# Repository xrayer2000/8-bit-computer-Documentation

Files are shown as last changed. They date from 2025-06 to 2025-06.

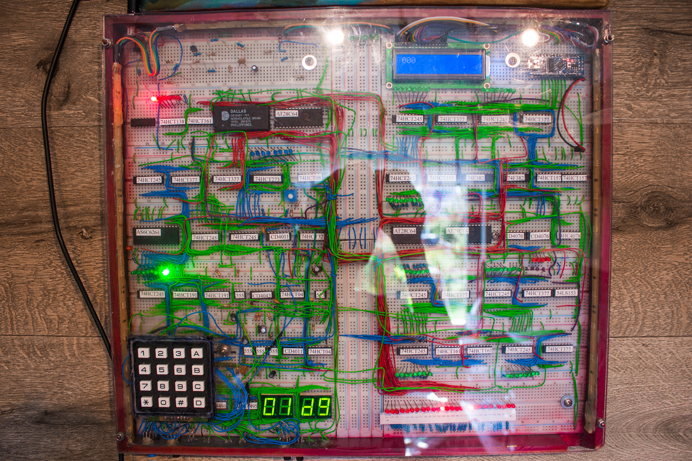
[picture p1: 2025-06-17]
Pictures/8-bit computer.jpg

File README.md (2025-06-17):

# LICENSE

## README

This project is licensed under the Creative Commons Attribution-NonCommercial 4.0 International License (CC BY-NC 4.0).

You are free to:
- Share (copy and redistribute the material in any medium or format)
- Adapt (remix, transform, and build upon the material)

Under the conditions that:
- You must give appropriate credit.
- You may not use the material for commercial purposes.

For full license details, see:  
[https://creativecommons.org/licenses/by-nc/4.0/](https://creativecommons.org/licenses/by-nc/4.0/)

---

## Creative Commons Attribution-NonCommercial 4.0 International (CC BY-NC 4.0)

Copyright (c) 2025 Emil

You are free to:
- Share — copy and redistribute the material in any medium or format
- Adapt — remix, transform, and build upon the material

Under the following terms:
- **Attribution** — You must give appropriate credit, provide a link to the license, and indicate if changes were made.
- **NonCommercial** — You may not use the material for commercial purposes.

No additional restrictions — You may not apply legal terms or technological measures that restrict others from doing anything the license permits.

Full license text:  
[https://creativecommons.org/licenses/by-nc/4.0/legalcode](https://creativecommons.org/licenses/by-nc/4.0/legalcode)

---

## How to attribute

If you use or adapt this project, please include the following attribution:

> “Project name” by Emil is licensed under CC BY-NC 4.0.  
> [https://creativecommons.org/licenses/by-nc/4.0/](https://creativecommons.org/licenses/by-nc/4.0/)

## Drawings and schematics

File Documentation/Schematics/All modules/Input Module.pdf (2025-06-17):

## I/O Pins

## Debouncer to 191

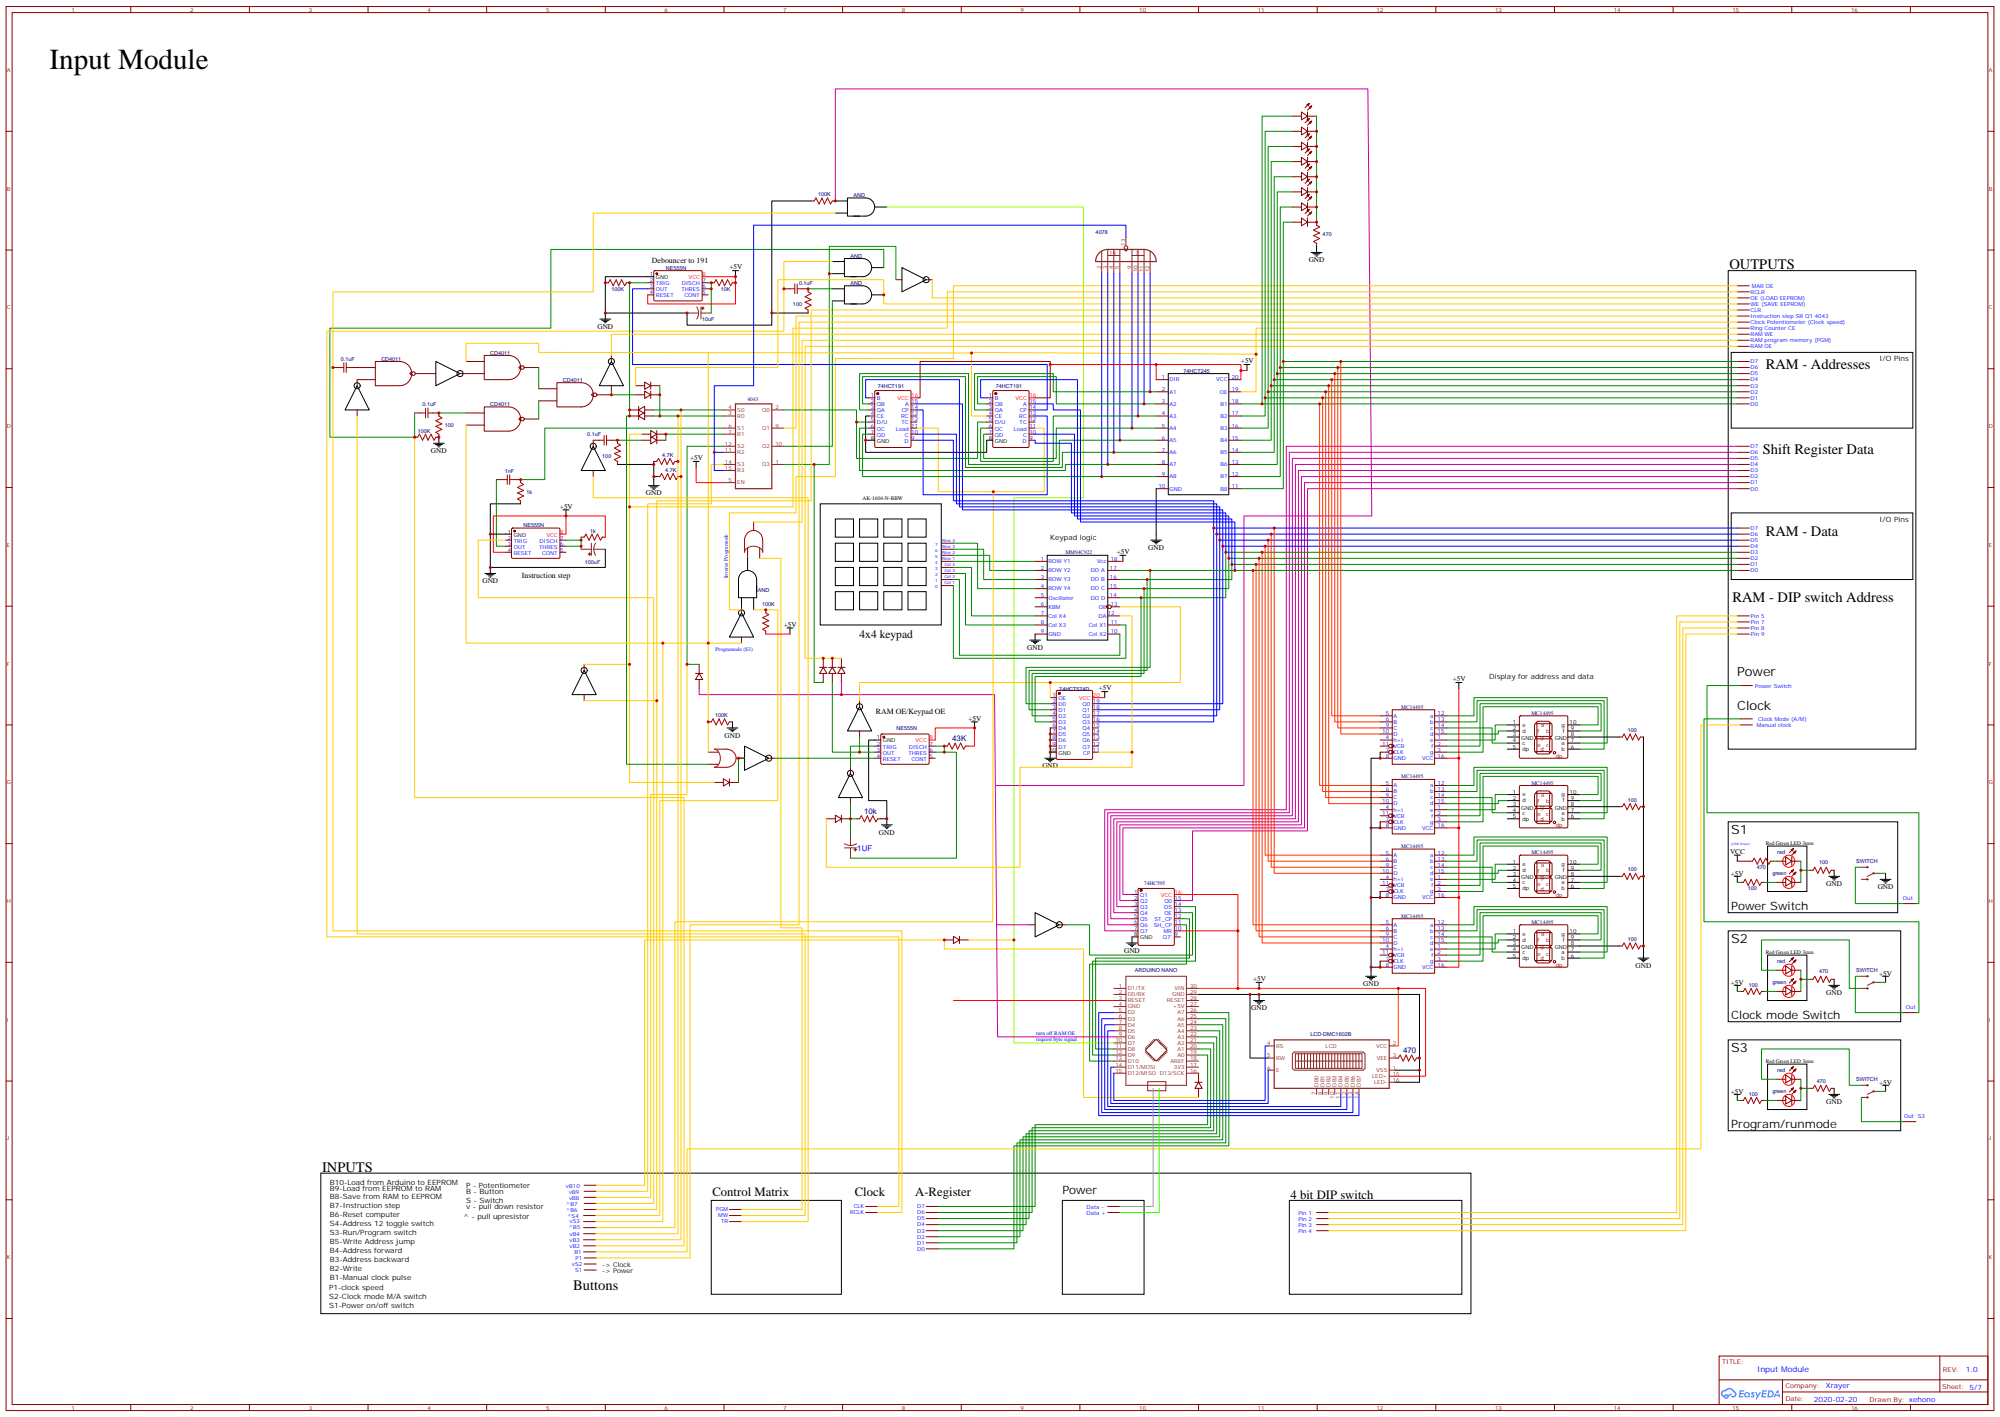
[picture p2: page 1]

Display for address and data

RAM OE/Keypad OE

turn off RAM OE
request byte signal

B10-Load from Arduino to EEPROM
B9-Load from EEPROM to RAM
B8-Save from RAM to EEPROM
B7-Instruction step
B6-Reset computer
S4-Address 12 toggle switch
S3-Run/Program switch
B5-Write Address jump
B4-Address forward
B3-Address backward
B2-Write
B1-Manual clock pulse
P1-clock speed
S2-Clock mode M/A switch
S1-Power on/off switch

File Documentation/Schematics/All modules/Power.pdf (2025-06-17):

# Power

# OUTPUTS

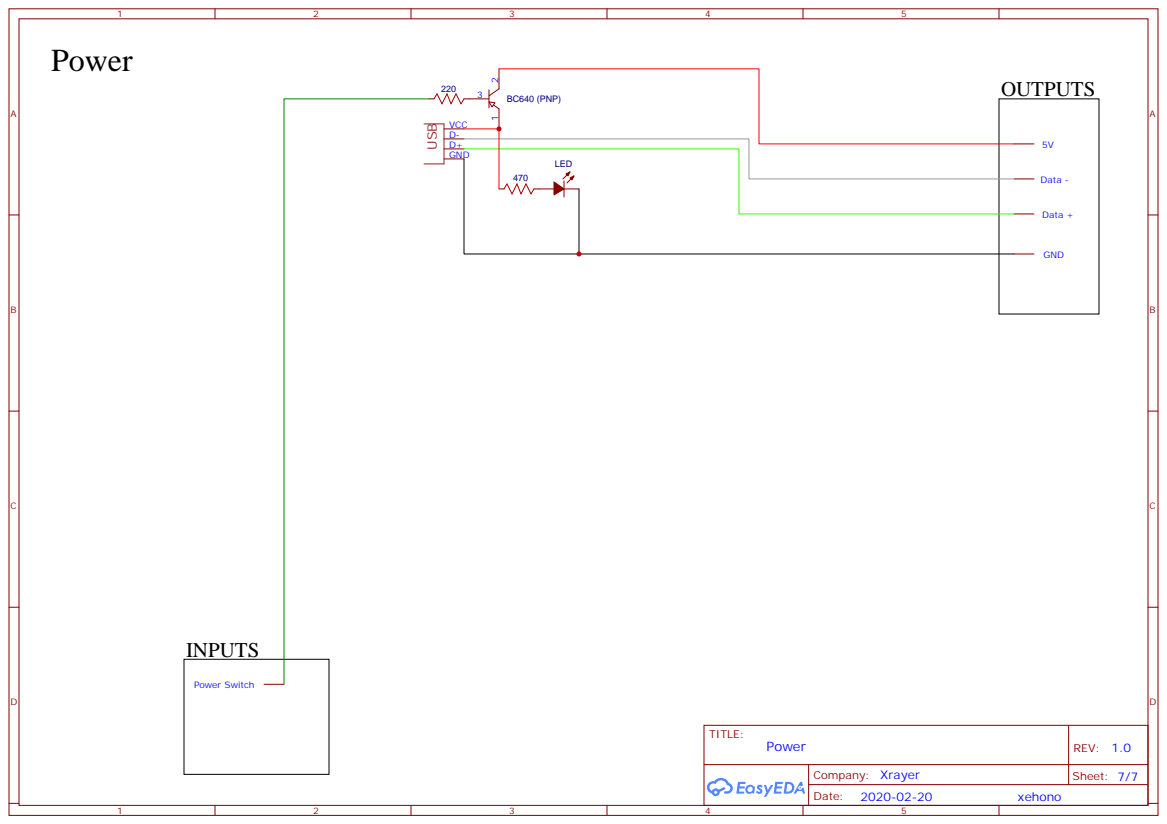
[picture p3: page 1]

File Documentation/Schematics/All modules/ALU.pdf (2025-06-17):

# ALU

# INPUTS

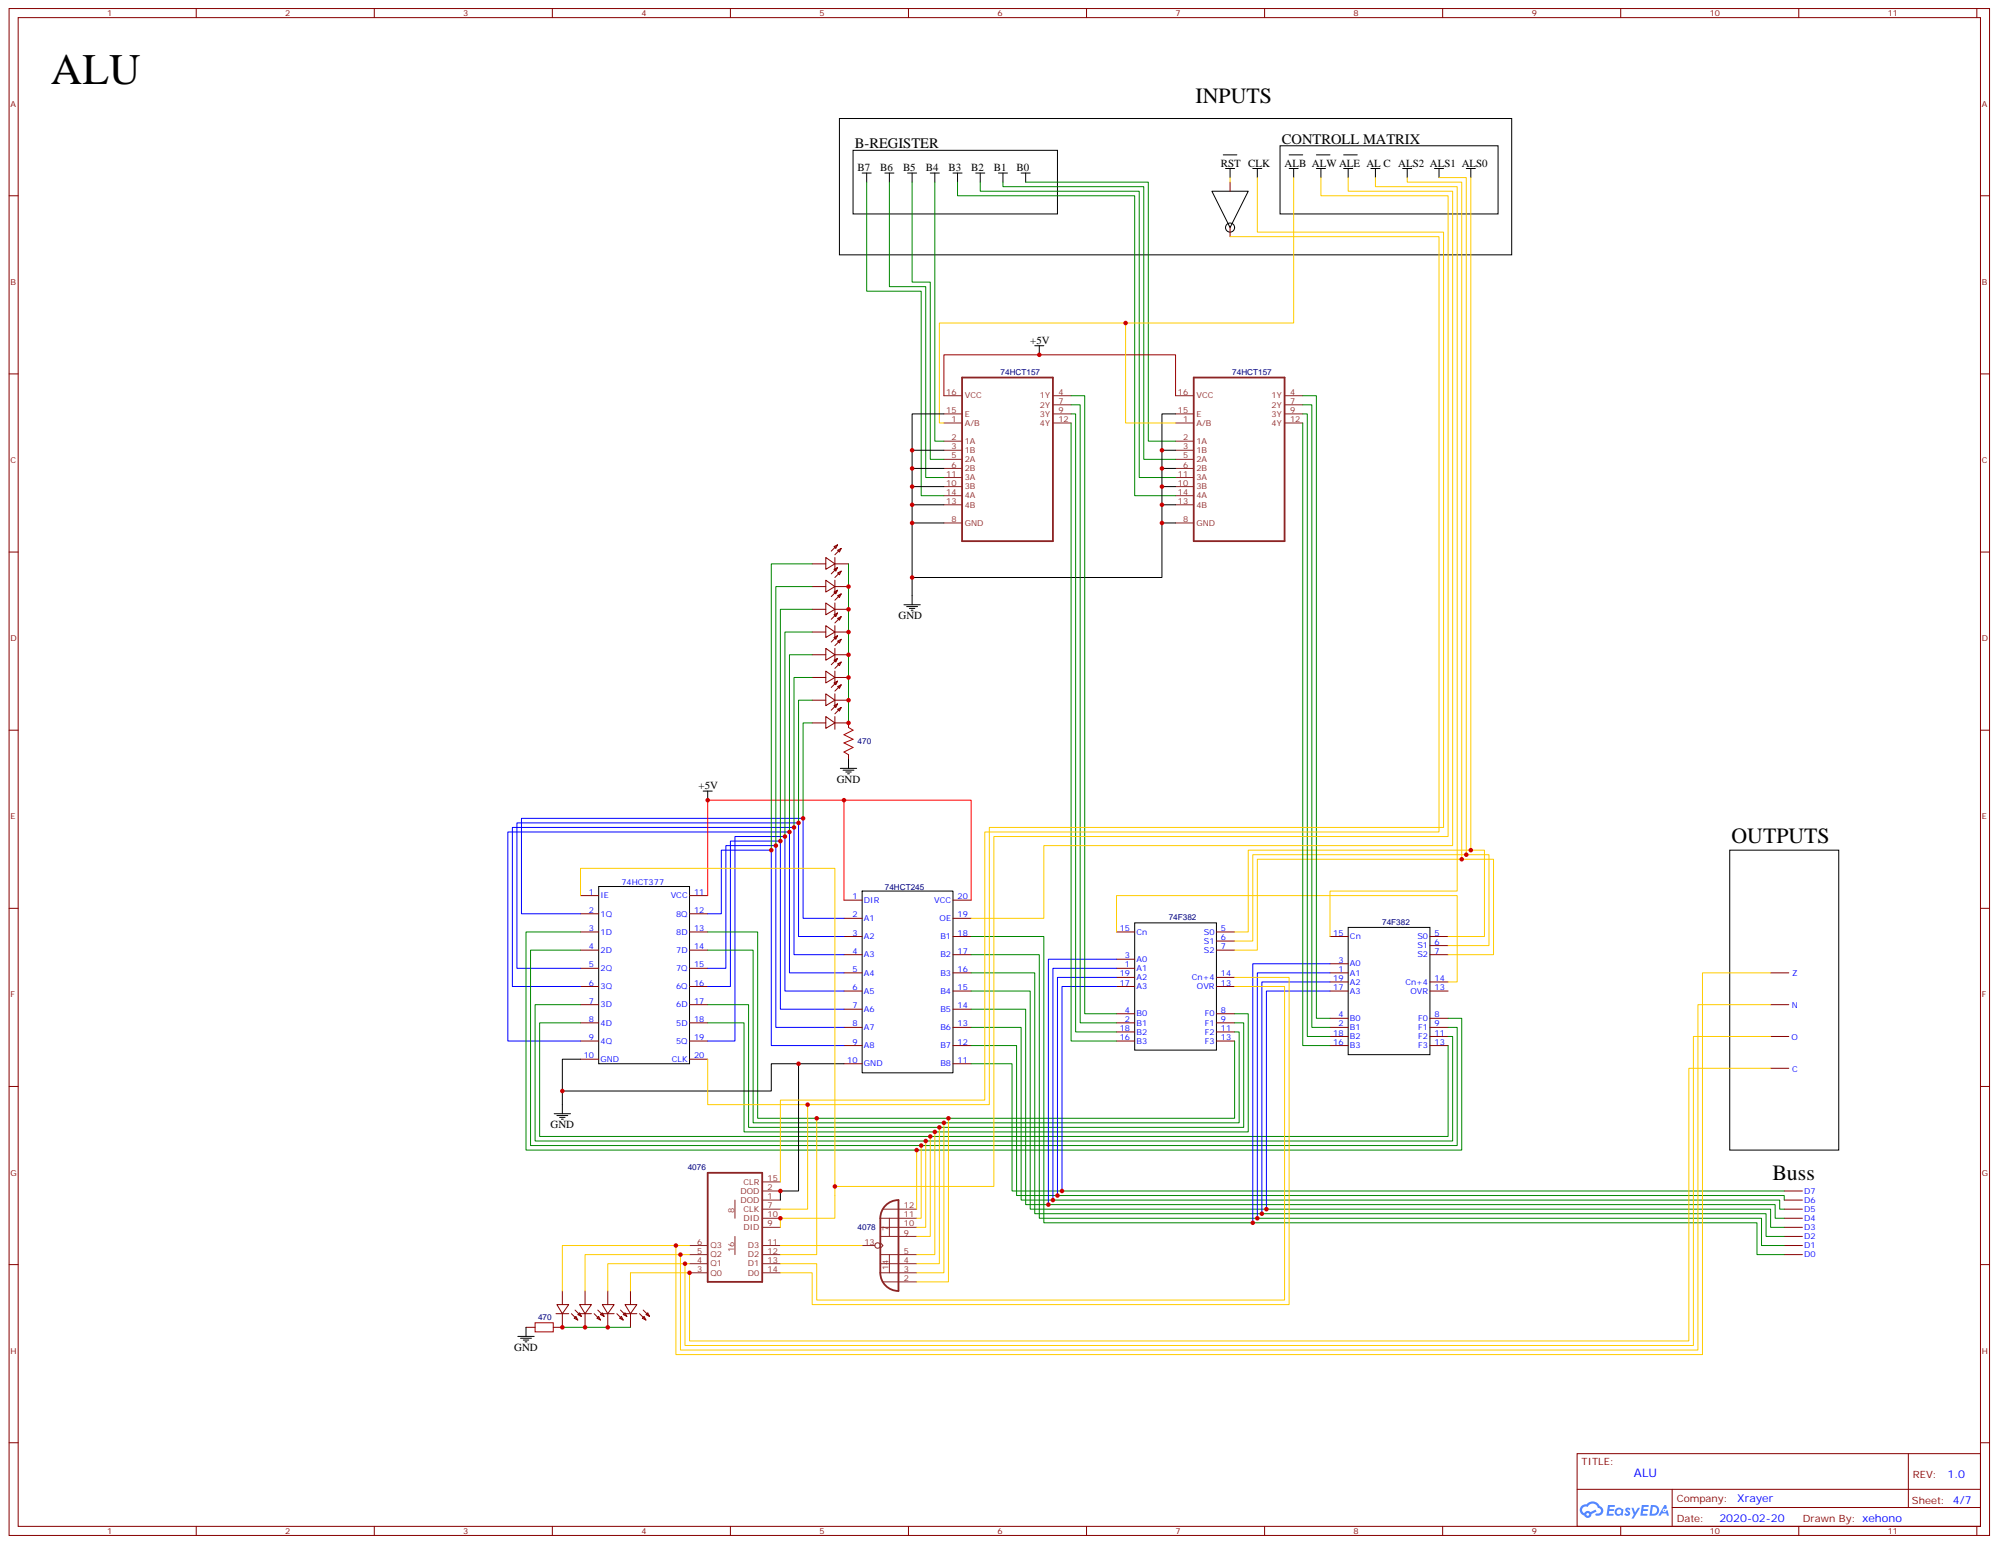
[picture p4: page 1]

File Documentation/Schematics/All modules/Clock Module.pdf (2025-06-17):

# OUTPUTS

# Clock Module

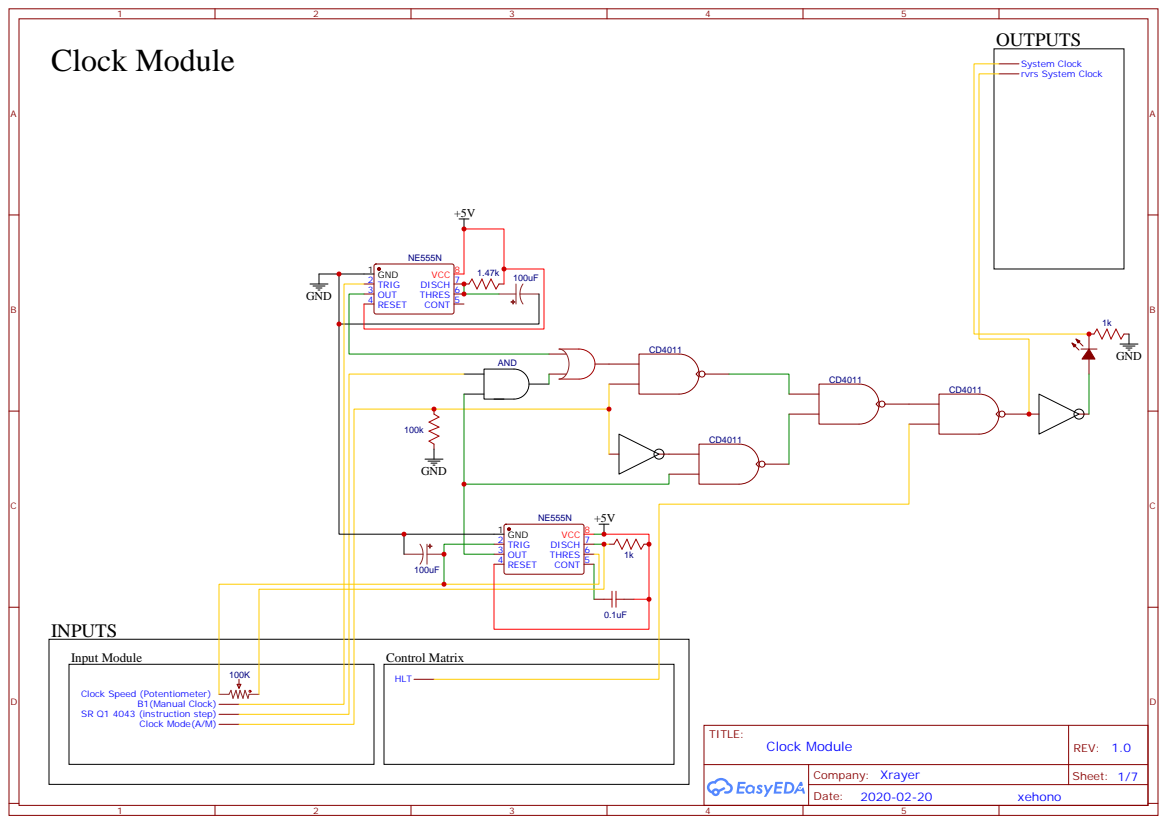
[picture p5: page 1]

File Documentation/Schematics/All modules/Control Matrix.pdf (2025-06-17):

## Control word

# Control Matrix

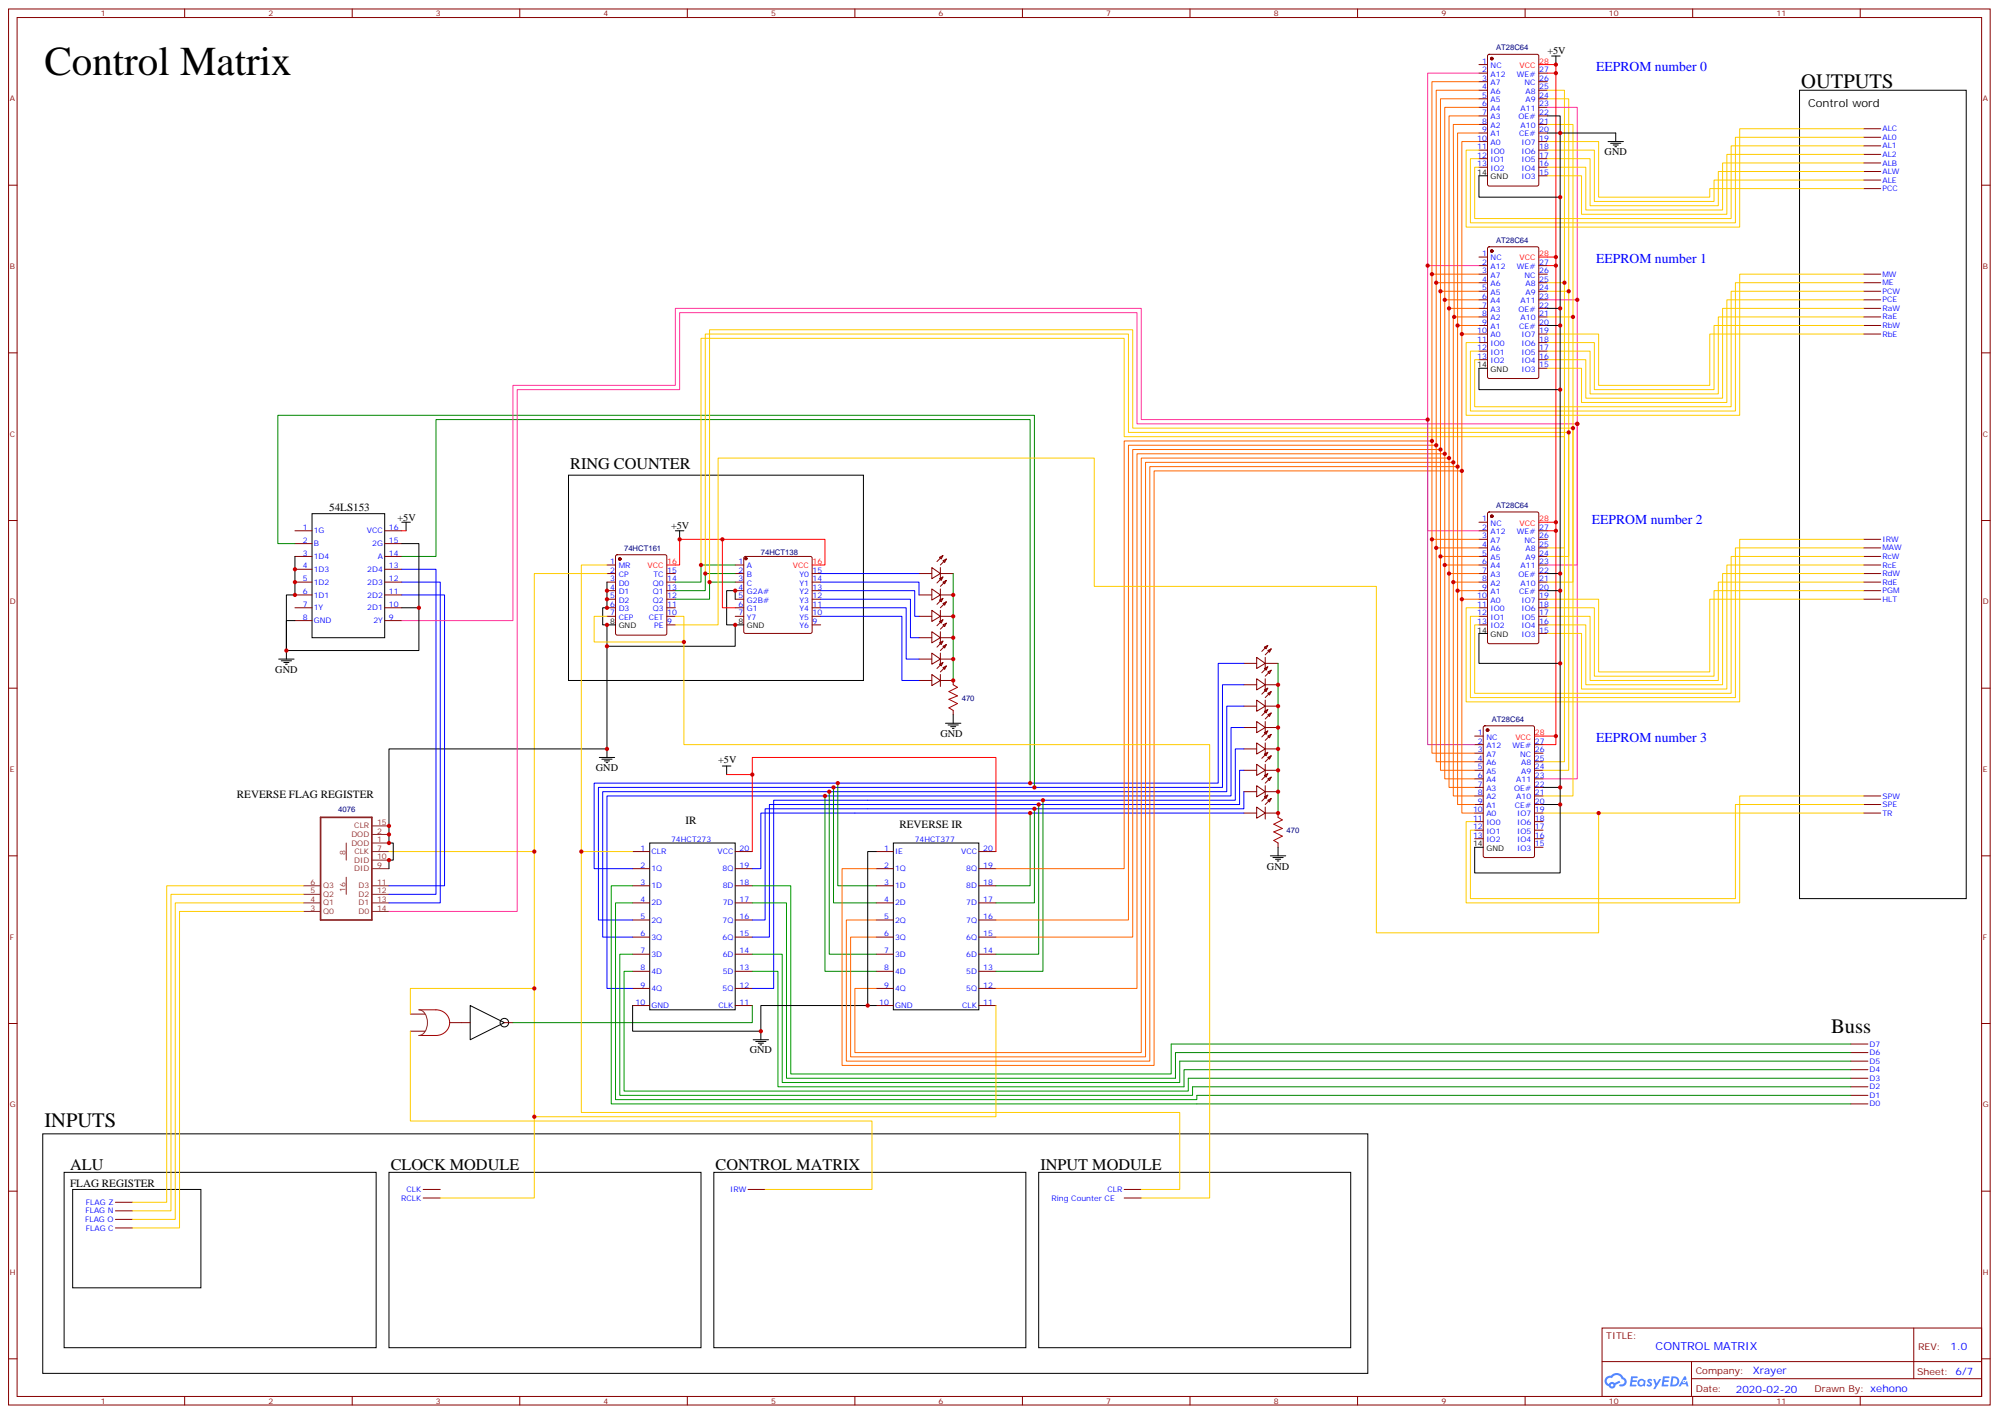
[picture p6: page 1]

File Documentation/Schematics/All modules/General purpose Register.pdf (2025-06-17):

# General purpose Register

# INPUTS

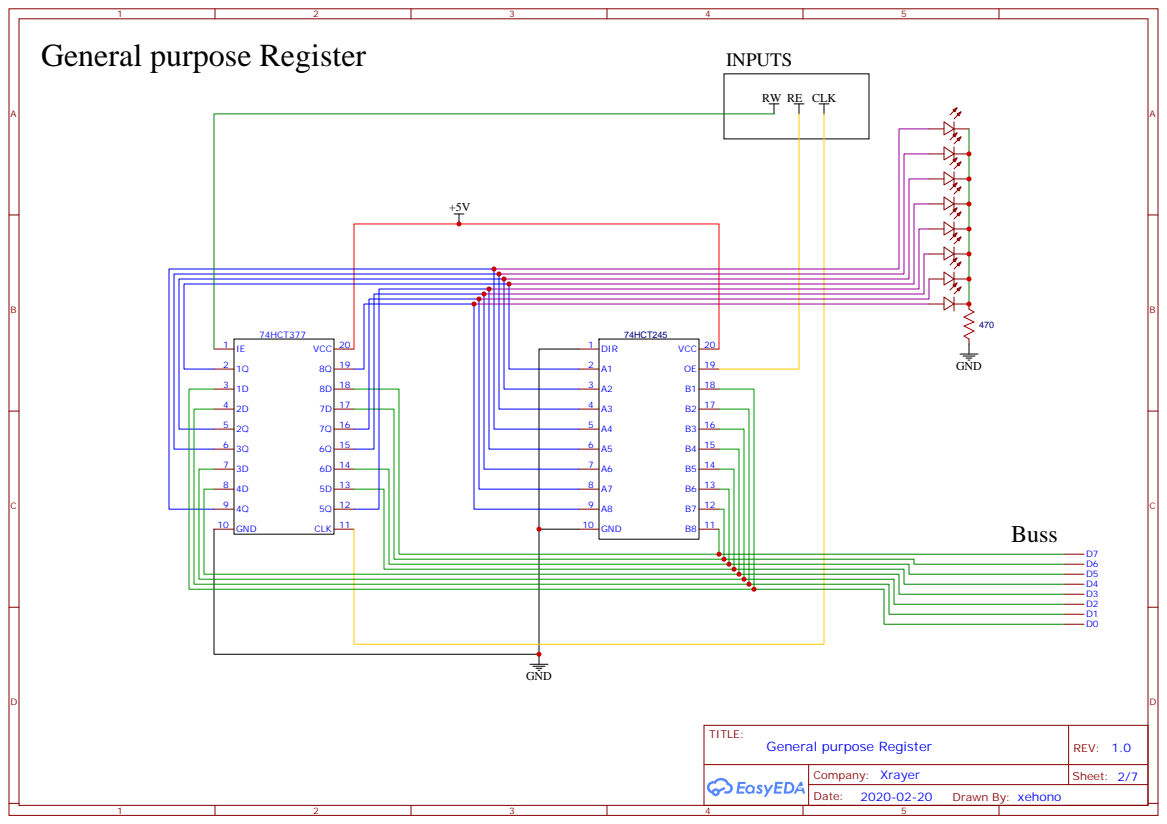
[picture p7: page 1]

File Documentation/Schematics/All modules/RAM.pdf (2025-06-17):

# MAR

# RAM

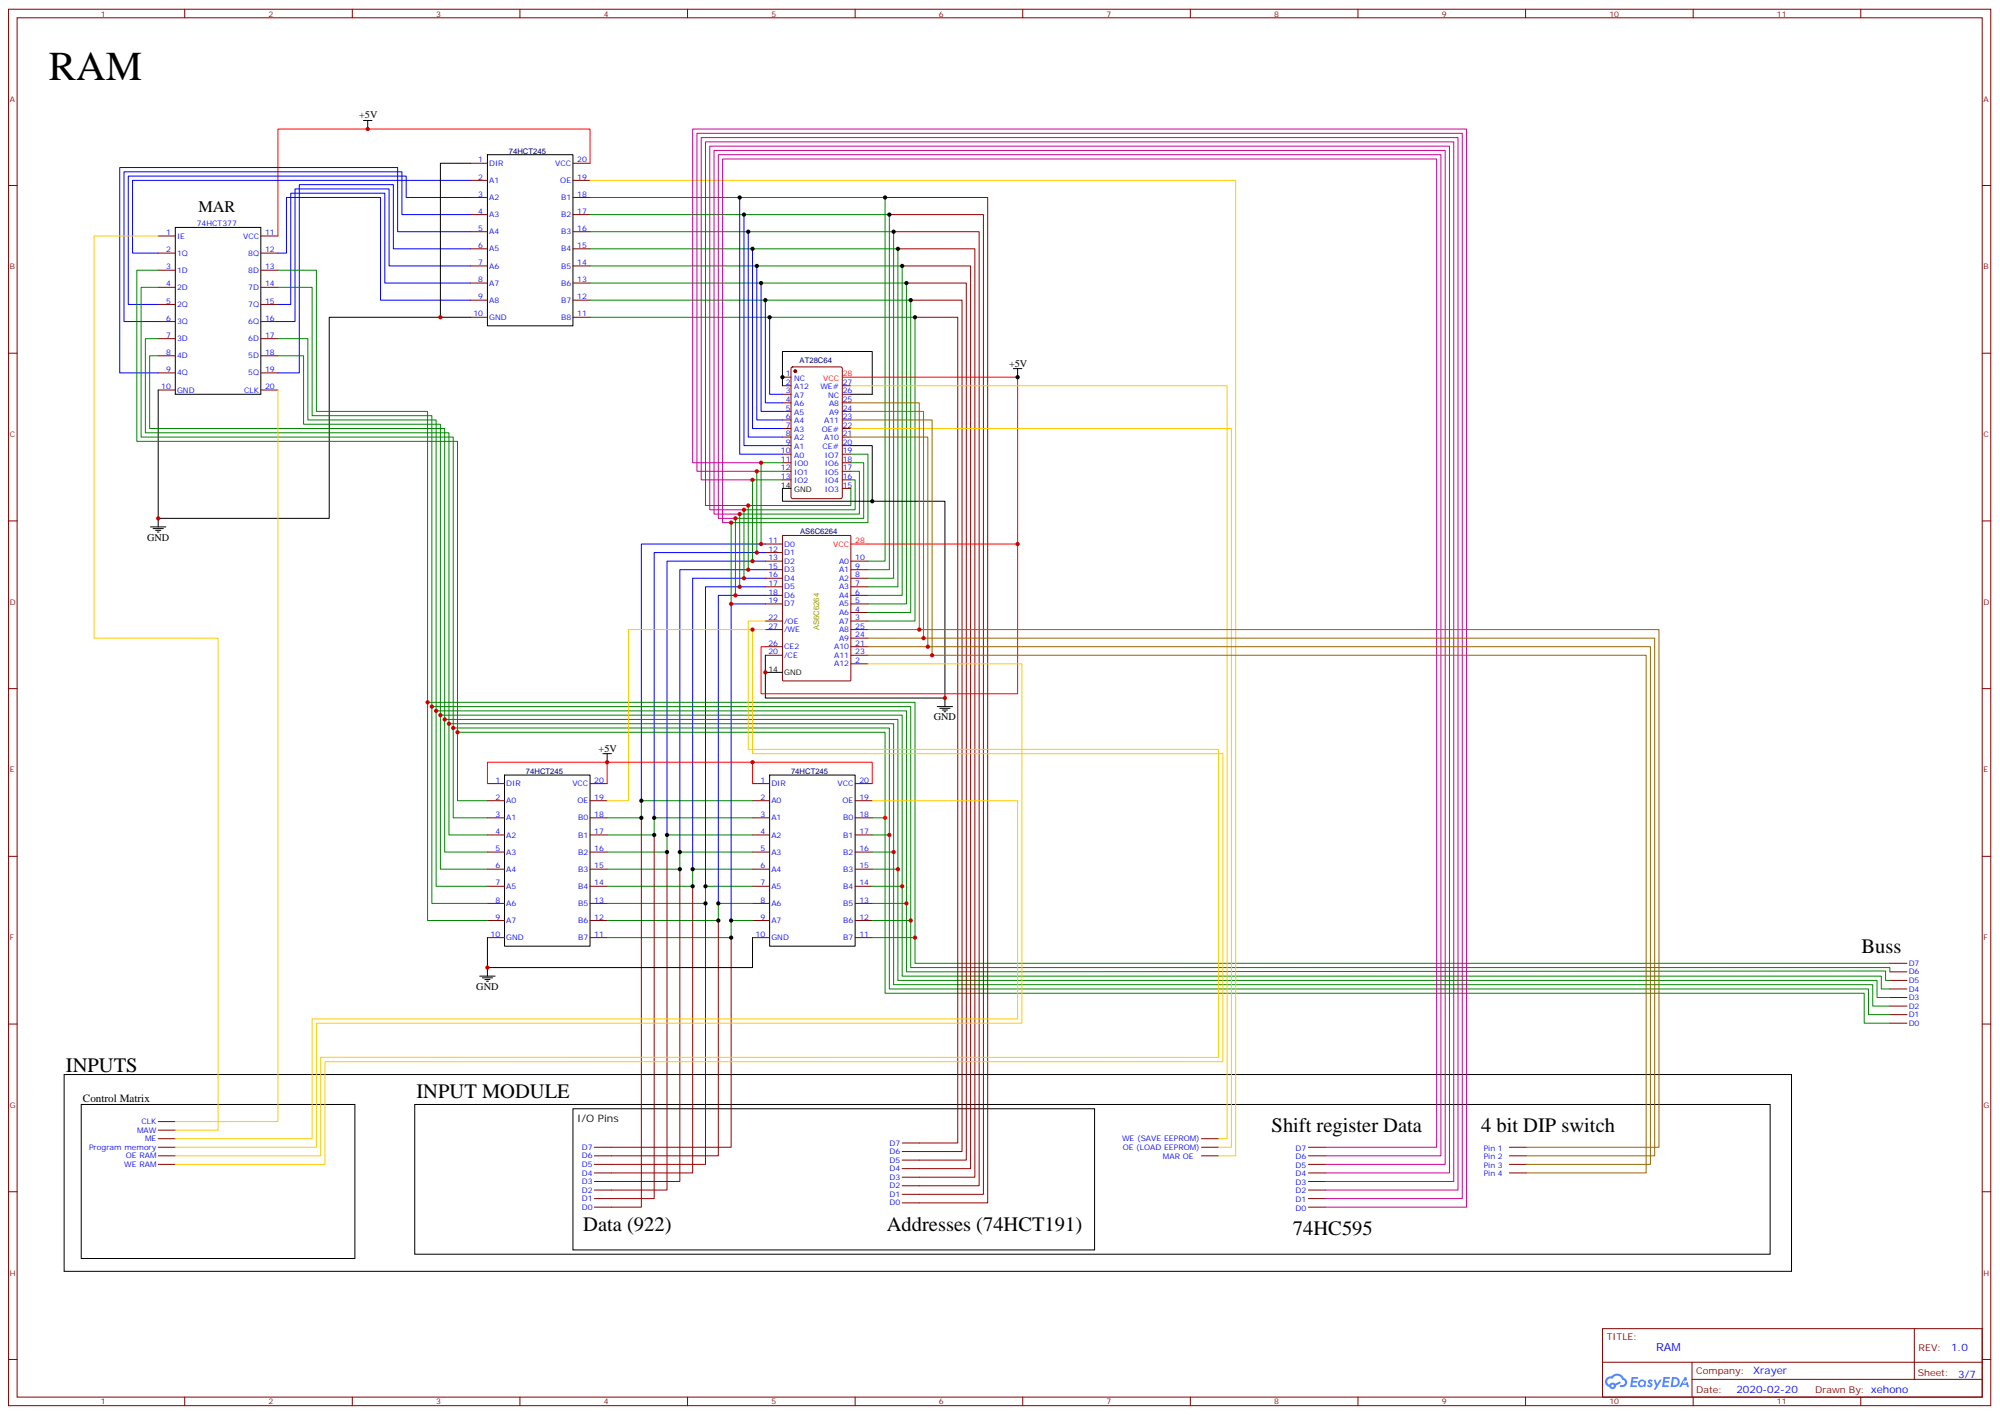
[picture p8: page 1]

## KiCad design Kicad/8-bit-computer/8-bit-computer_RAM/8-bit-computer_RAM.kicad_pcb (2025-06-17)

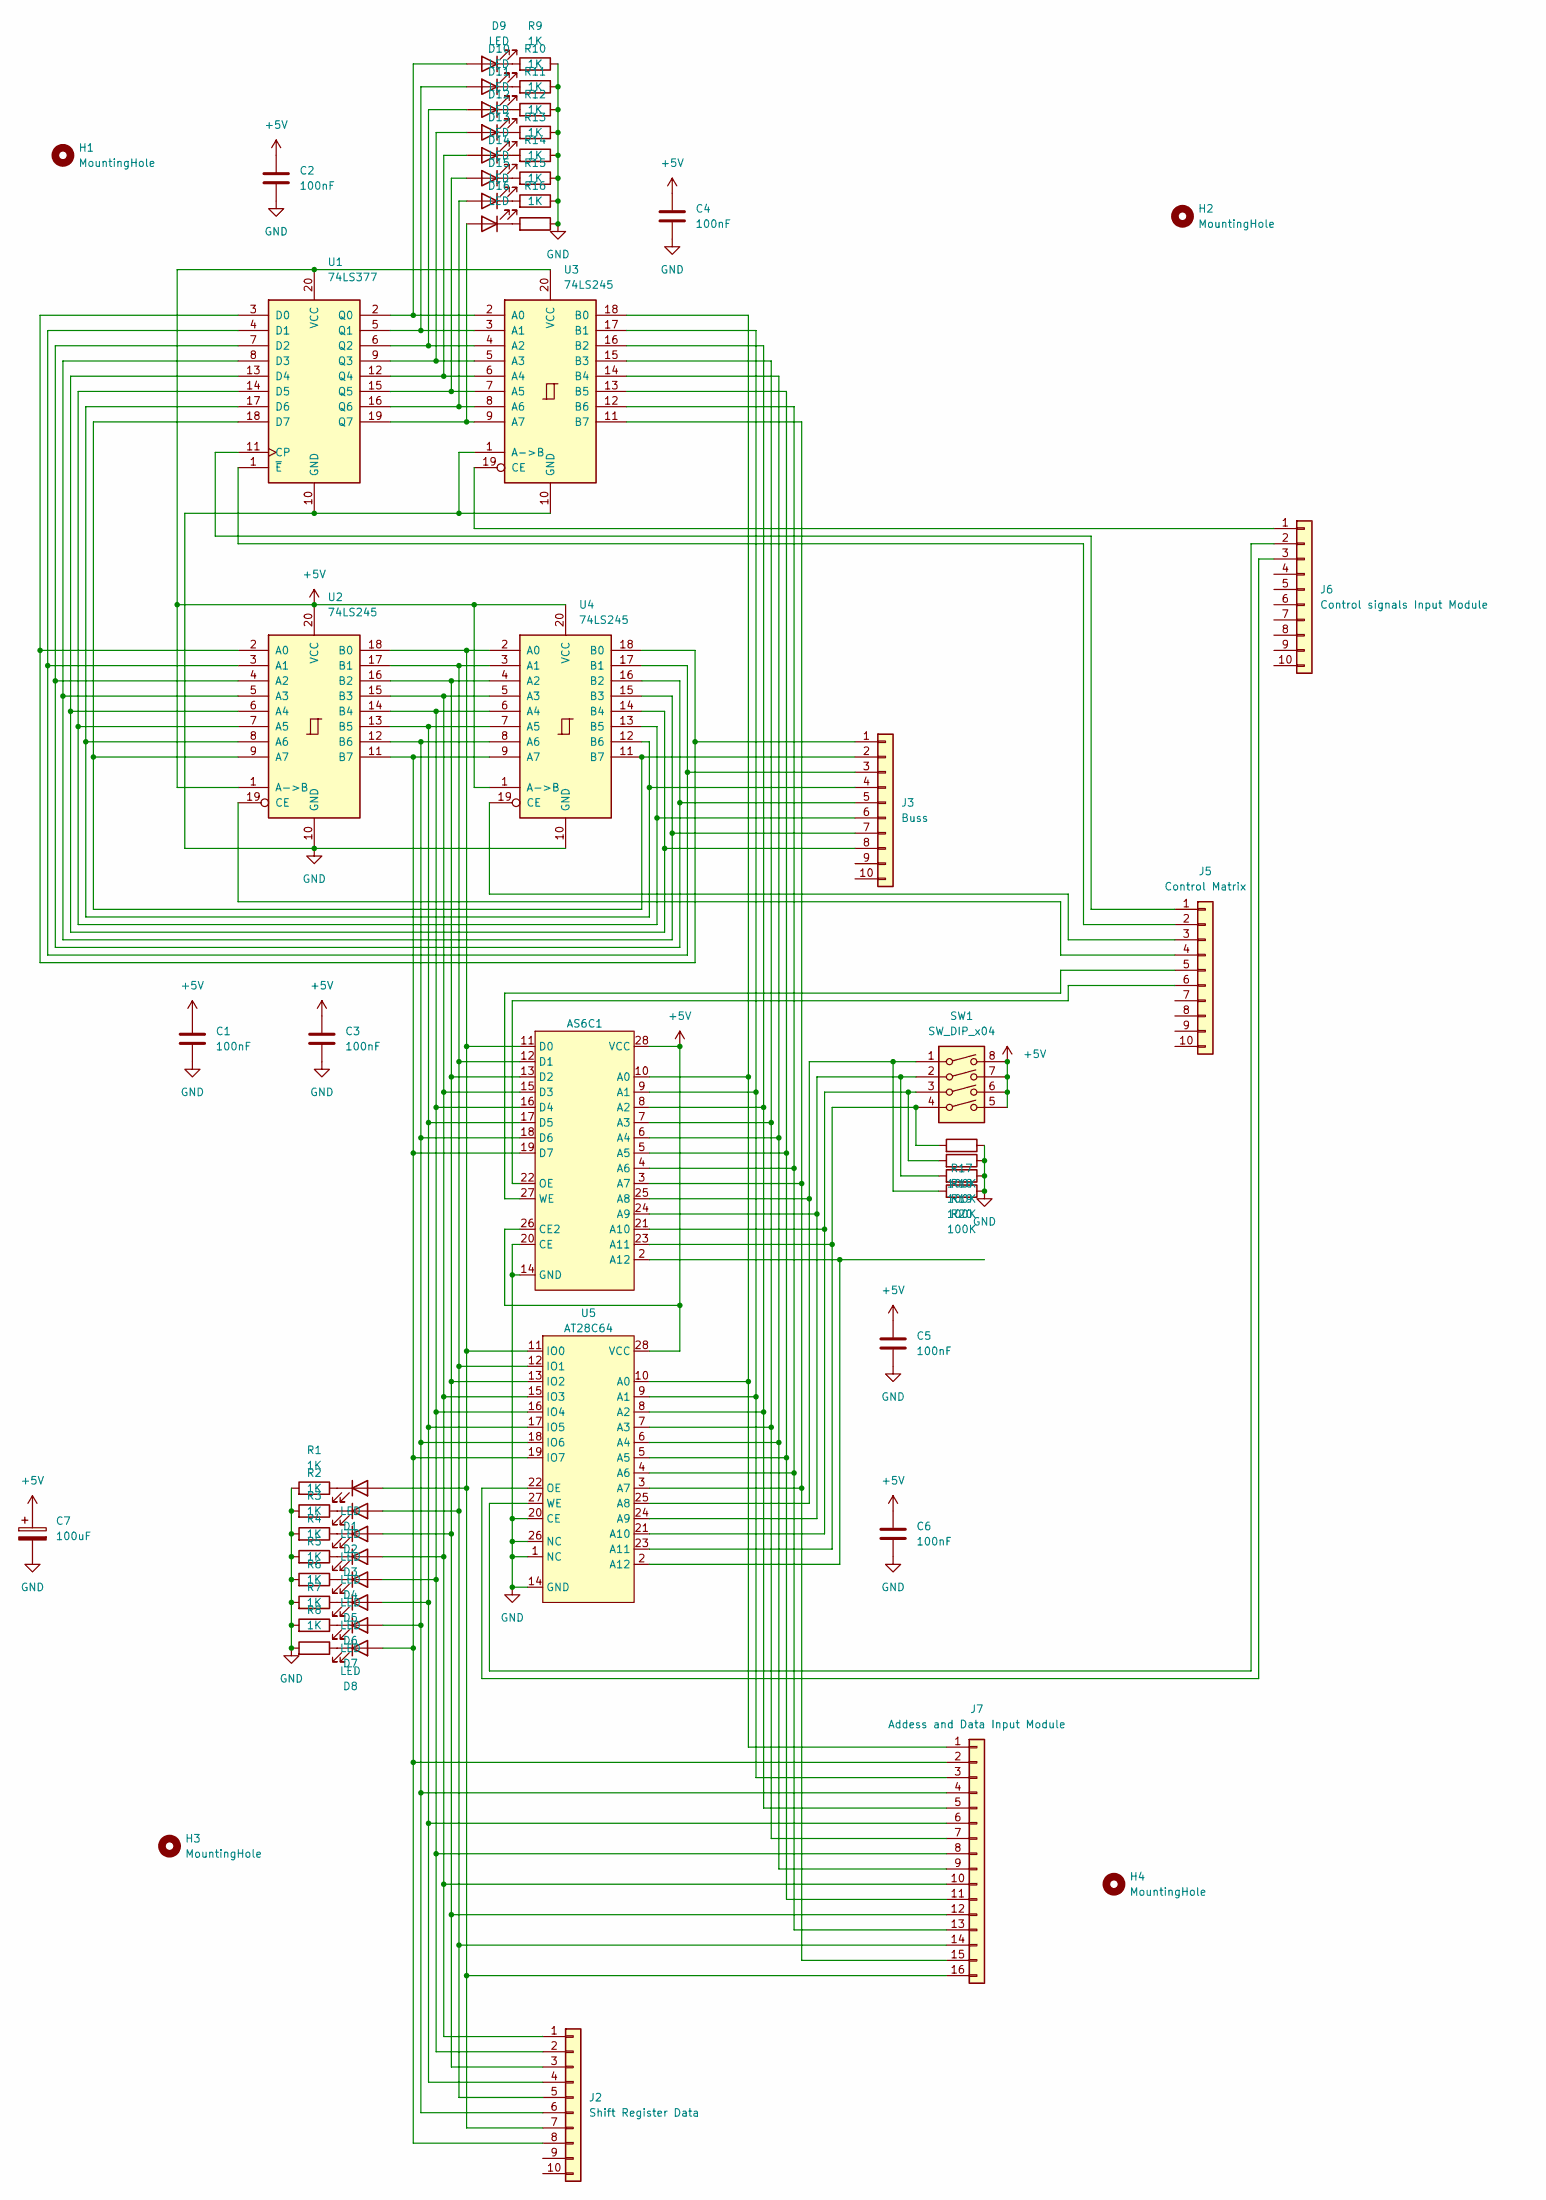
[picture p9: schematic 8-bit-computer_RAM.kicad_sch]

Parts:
AS6C1: DIP-28_W15.24mm_Socket
C1, C2, C3, C4, C5, C6: 100nF; C_Disc_D3.0mm_W1.6mm_P2.50mm
C7: 100uF; CP_Radial_D4.0mm_P2.00mm
D1, D2, D3, D4, D5, D6, D7, D8, D9, D10, D11, D12, D13, D14, D15, D16: LED; LED_D3.0mm
H1, H2, H3, H4: MountingHole; MountingHole_3.2mm_M3_DIN965_Pad
J2: Shift Register Data; IDC-Header_2x05_P2.54mm_Vertical
J3: Buss; IDC-Header_2x05_P2.54mm_Vertical
J5: Control Matrix; IDC-Header_2x05_P2.54mm_Vertical
J6: Control signals Input Module; IDC-Header_2x05_P2.54mm_Vertical
J7: Addess and Data Input Module; IDC-Header_2x08_P2.54mm_Vertical
R1, R2, R3, R4, R5, R6, R7, R8, R9, R10, R11, R12, R13, R14, R15, R16: 1K; R_Axial_DIN0207_L6.3mm_D2.5mm_P7.62mm_Horizontal
R17, R18, R19, R20: 100K; R_Axial_DIN0207_L6.3mm_D2.5mm_P7.62mm_Horizontal
SW1: SW_DIP_x04; SW_DIP_SPSTx04_Slide_9.78x12.34mm_W7.62mm_P2.54mm
U1: 74LS377; DIP-20_W7.62mm_Socket
U2, U3, U4: 74LS245; DIP-20_W7.62mm_Socket
U5: AT28C64; DIP-28_W15.24mm_Socket

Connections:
+5V: AS6C1.26 (CE2), AS6C1.28 (VCC), C1.1, C2.1, C3.1, C4.1, C5.1, C6.1, C7.1, SW1.5, SW1.6, SW1.7, SW1.8, U1.20 (VCC), U2.1 (A->B), U2.20 (VCC), U3.20 (VCC), U4.1 (A->B), U4.20 (VCC), U5.28 (VCC)
GND: AS6C1.14 (GND), AS6C1.20 (CE), C1.2, C2.2, C3.2, C4.2, C5.2, C6.2, C7.2, R1.2, R2.2, R3.2, R4.2, R5.2, R6.2, R7.2, R8.2, R9.1, R10.1, R11.1, R12.1, R13.1, R14.1, R15.1, R16.1, R17.1, R18.1, R19.1, R20.1, U1.10 (GND), U2.10 (GND), U3.1 (A->B), U3.10 (GND), U4.10 (GND), U5.1 (NC), U5.14 (GND), U5.20 (CE), U5.26 (NC)
unnamed: AS6C1.10 (A0), J7.1, U3.18 (B0), U5.10 (A0)
unnamed: AS6C1.9 (A1), J7.3, U3.17 (B1), U5.9 (A1)
unnamed: AS6C1.8 (A2), J7.5, U3.16 (B2), U5.8 (A2)
unnamed: AS6C1.7 (A3), J7.7, U3.15 (B3), U5.7 (A3)
unnamed: AS6C1.6 (A4), J7.9, U3.14 (B4), U5.6 (A4)
unnamed: AS6C1.5 (A5), J7.11, U3.13 (B5), U5.5 (A5)
unnamed: AS6C1.4 (A6), J7.13, U3.12 (B6), U5.4 (A6)
unnamed: AS6C1.3 (A7), J7.15, U3.11 (B7), U5.3 (A7)
unnamed: AS6C1.25 (A8), R20.2, SW1.1, U5.25 (A8)
unnamed: AS6C1.24 (A9), R19.2, SW1.2, U5.24 (A9)
unnamed: AS6C1.21 (A10), R18.2, SW1.3, U5.21 (A10)
unnamed: AS6C1.23 (A11), R17.2, SW1.4, U5.23 (A11)
unnamed: AS6C1.2 (A12), U5.2 (A12)
unnamed: AS6C1.11 (D0), D1.2 (A), J2.7, J7.16, U2.18 (B0), U4.2 (A0), U5.11 (IO0)
unnamed: AS6C1.12 (D1), D2.2 (A), J2.5, J7.14, U2.17 (B1), U4.3 (A1), U5.12 (IO1)
unnamed: AS6C1.13 (D2), D3.2 (A), J2.3, J7.12, U2.16 (B2), U4.4 (A2), U5.13 (IO2)
unnamed: AS6C1.15 (D3), D4.2 (A), J2.1, J7.10, U2.15 (B3), U4.5 (A3), U5.15 (IO3)
unnamed: AS6C1.16 (D4), D5.2 (A), J2.2, J7.8, U2.14 (B4), U4.6 (A4), U5.16 (IO4)
unnamed: AS6C1.17 (D5), D6.2 (A), J2.4, J7.6, U2.13 (B5), U4.7 (A5), U5.17 (IO5)
unnamed: AS6C1.18 (D6), D7.2 (A), J2.6, J7.4, U2.12 (B6), U4.8 (A6), U5.18 (IO6)
unnamed: AS6C1.19 (D7), D8.2 (A), J2.8, J7.2, U2.11 (B7), U4.9 (A7), U5.19 (IO7)
unnamed: AS6C1.22 (OE), J5.6
unnamed: AS6C1.27 (WE), J5.5
unnamed: D1.1 (K), R1.1
unnamed: D2.1 (K), R2.1
unnamed: D3.1 (K), R3.1
unnamed: D4.1 (K), R4.1
unnamed: D5.1 (K), R5.1
unnamed: D6.1 (K), R6.1
unnamed: D7.1 (K), R7.1
unnamed: D8.1 (K), R8.1
unnamed: D9.2 (A), U1.2 (Q0), U3.2 (A0)
unnamed: D9.1 (K), R9.2
unnamed: D10.2 (A), U1.5 (Q1), U3.3 (A1)
unnamed: D10.1 (K), R10.2
unnamed: D11.2 (A), U1.6 (Q2), U3.4 (A2)
unnamed: D11.1 (K), R11.2
unnamed: D12.2 (A), U1.9 (Q3), U3.5 (A3)
unnamed: D12.1 (K), R12.2
unnamed: D13.2 (A), U1.12 (Q4), U3.6 (A4)
unnamed: D13.1 (K), R13.2
unnamed: D14.2 (A), U1.15 (Q5), U3.7 (A5)
unnamed: D14.1 (K), R14.2
unnamed: D15.2 (A), U1.16 (Q6), U3.8 (A6)
unnamed: D15.1 (K), R15.2
unnamed: D16.2 (A), U1.19 (Q7), U3.9 (A7)
unnamed: D16.1 (K), R16.2
unnamed: J3.1, U1.3 (D0), U2.2 (A0), U4.18 (B0)
unnamed: J3.2, U1.18 (D7), U2.9 (A7), U4.11 (B7)
unnamed: J3.3, U1.4 (D1), U2.3 (A1), U4.17 (B1)
unnamed: J3.4, U1.17 (D6), U2.8 (A6), U4.12 (B6)
unnamed: J3.5, U1.7 (D2), U2.4 (A2), U4.16 (B2)
unnamed: J3.6, U1.14 (D5), U2.7 (A5), U4.13 (B5)
unnamed: J3.7, U1.8 (D3), U2.5 (A3), U4.15 (B3)
unnamed: J3.8, U1.13 (D4), U2.6 (A4), U4.14 (B4)
unnamed: J5.1, U1.11 (CP)
unnamed: J5.2, U1.1 (~E)
unnamed: J5.3, U4.19 (CE)
unnamed: J5.4, U2.19 (CE)
unnamed: J6.1, U3.19 (CE)
unnamed: J6.2, U5.27 (WE)
unnamed: J6.3, U5.22 (OE)

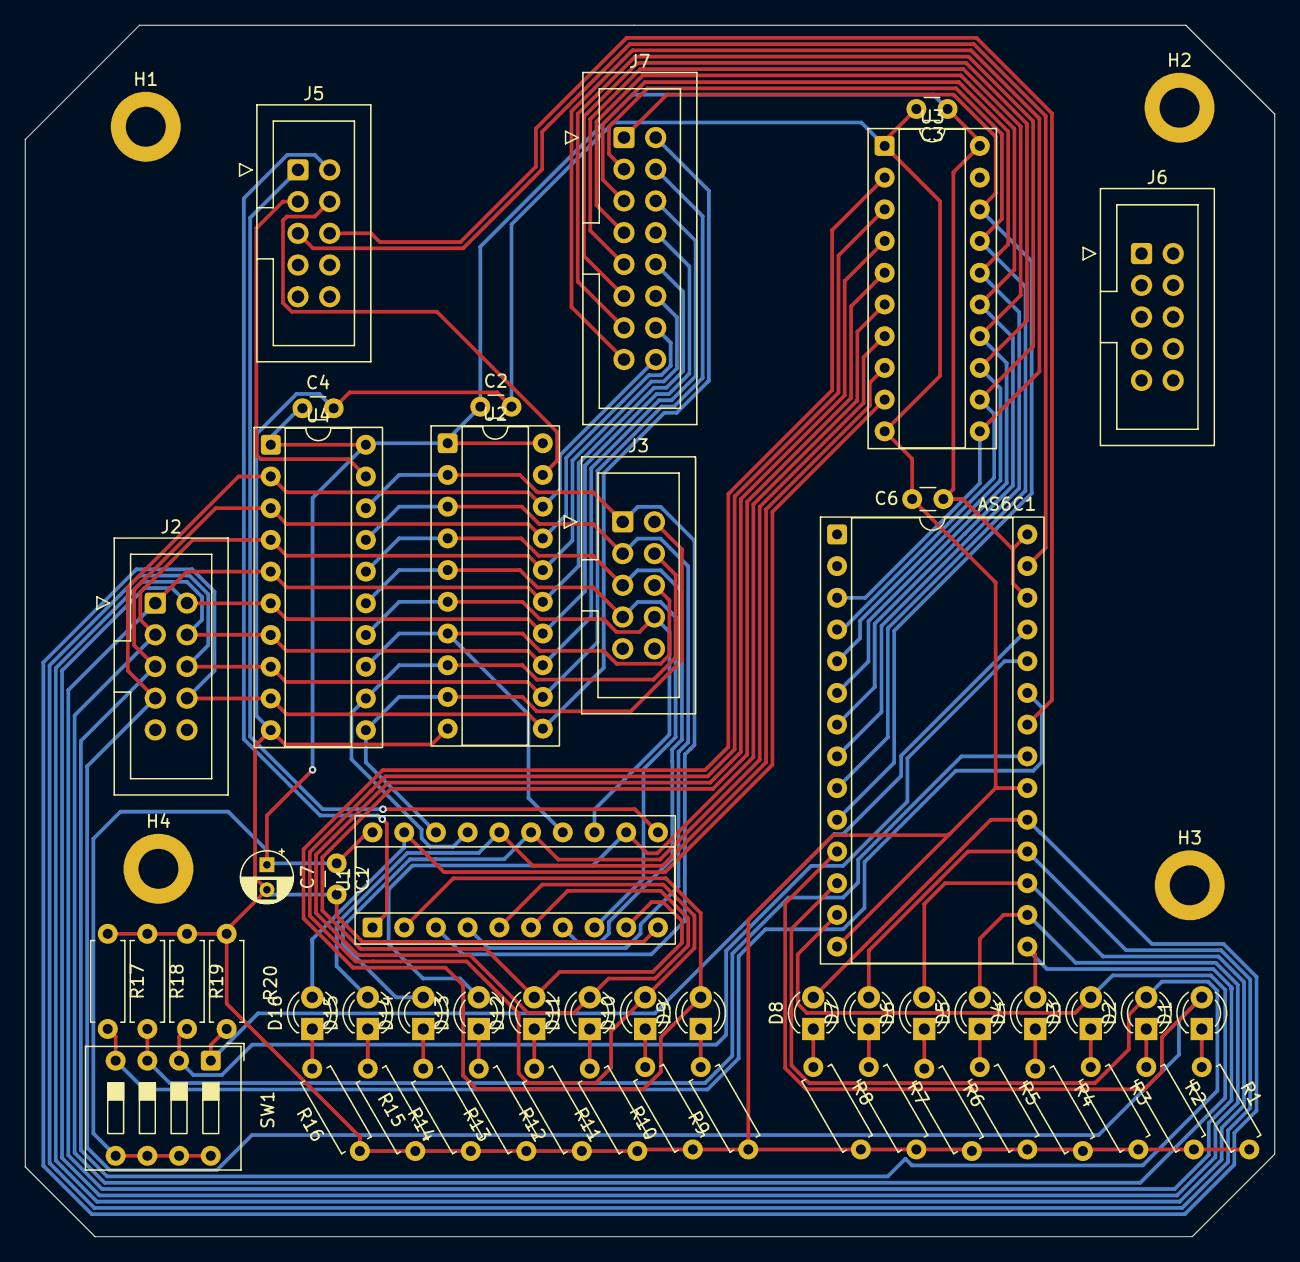
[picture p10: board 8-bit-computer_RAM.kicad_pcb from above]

Board: 2 copper layers, 100.1 x 97.0 mm, 57 parts (0 on the bottom side), 61 nets.

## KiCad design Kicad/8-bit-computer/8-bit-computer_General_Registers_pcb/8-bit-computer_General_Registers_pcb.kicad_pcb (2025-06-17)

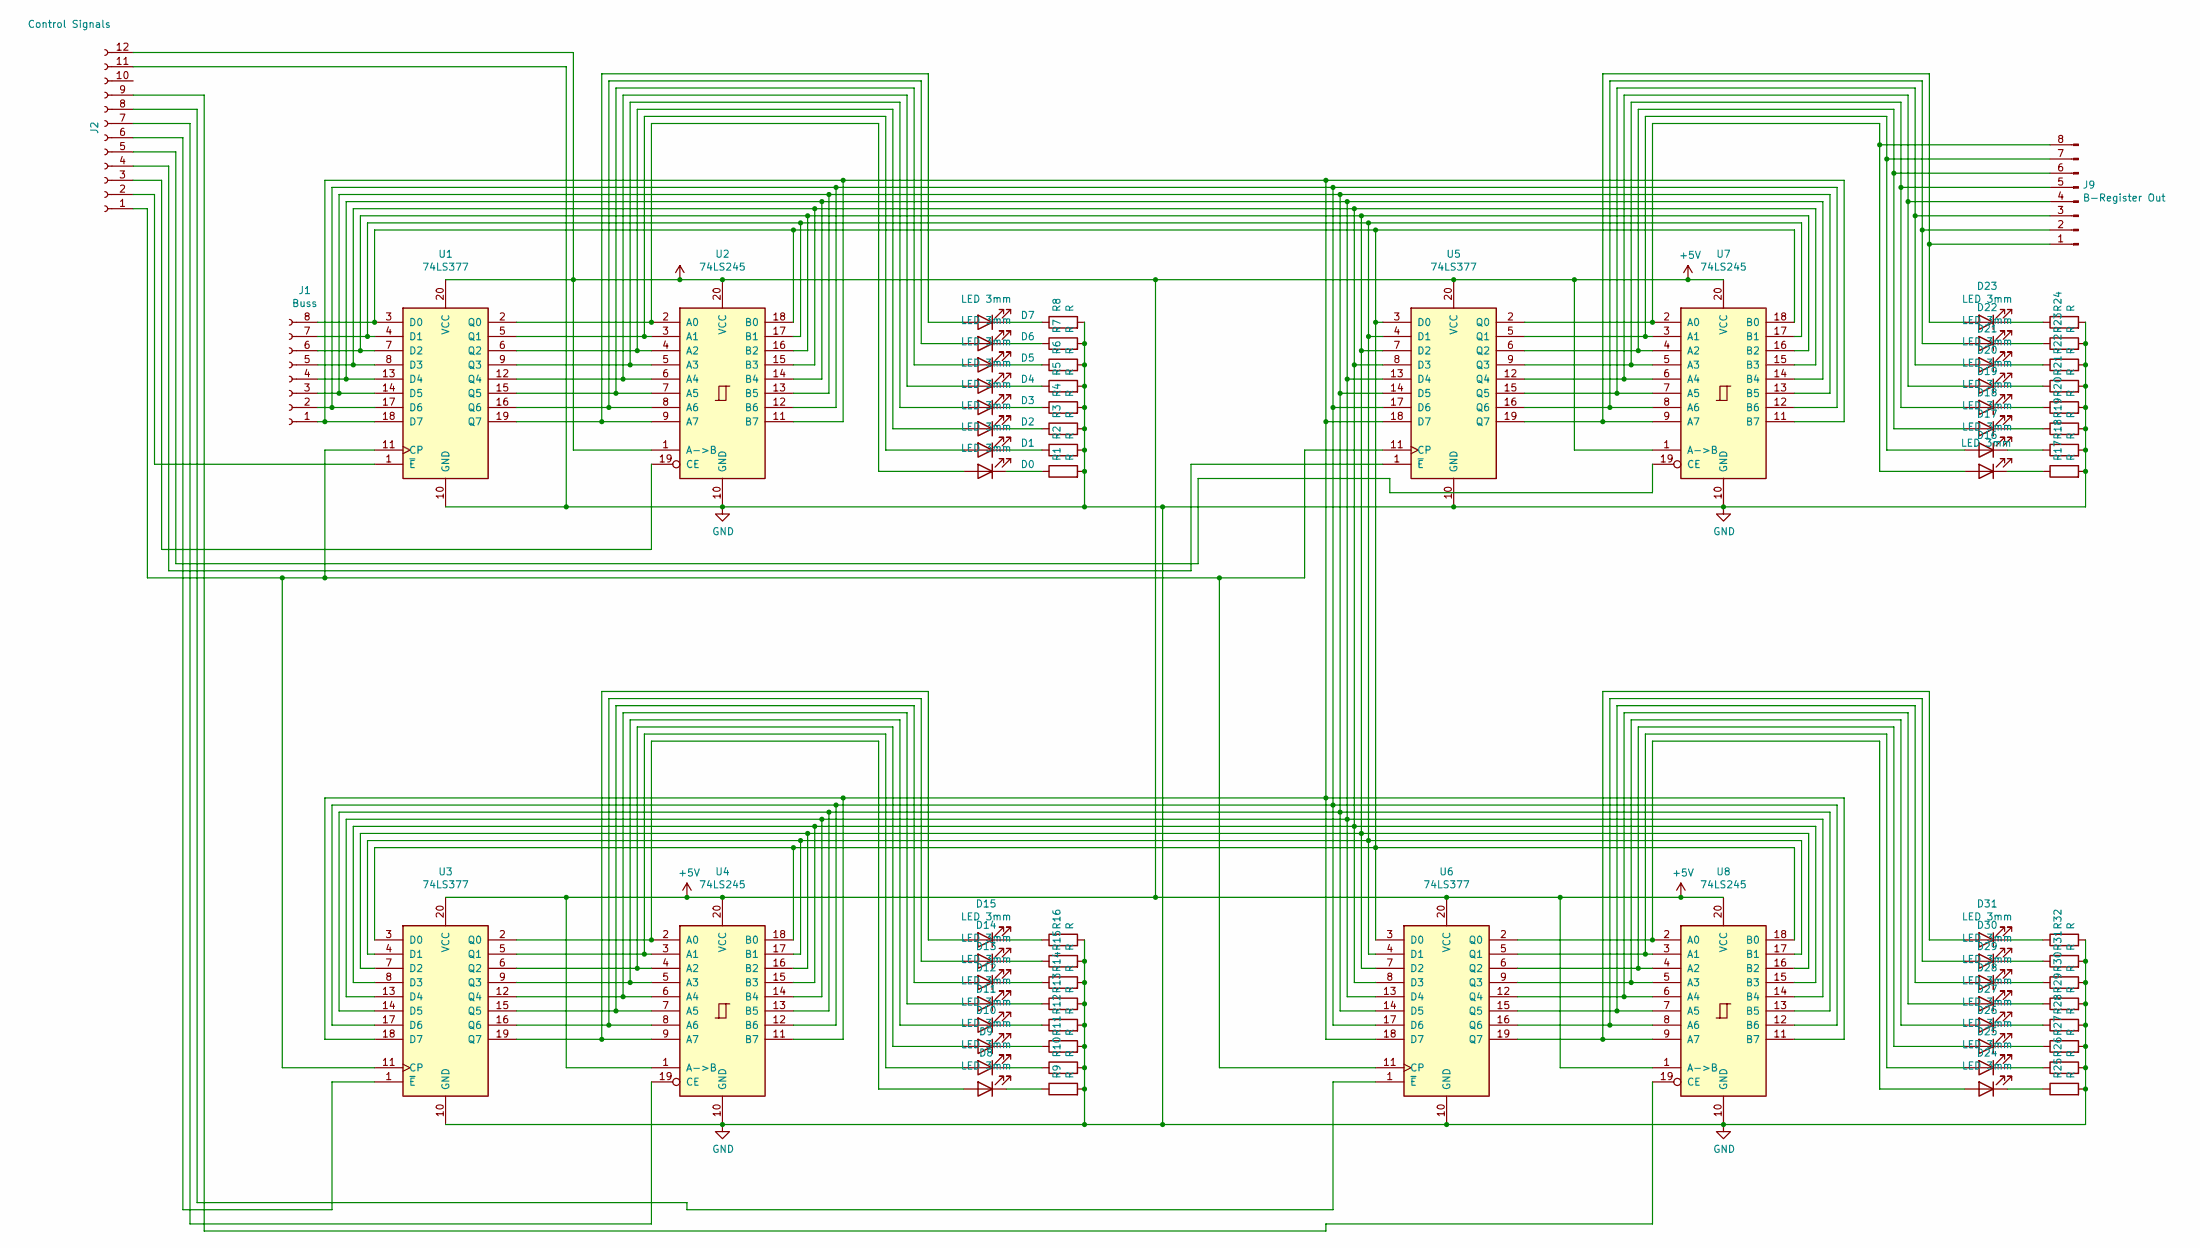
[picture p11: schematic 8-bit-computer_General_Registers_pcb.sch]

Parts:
D0, D1, D2, D3, D4, D5, D6, D7, D8, D9, D10, D11, D12, D13, D14, D15, D16, D17, D18, D19, D20, D21, D22, D23, D24, D25, D26, D27, D28, D29, D30, D31: LED 3mm; LED_D3.0mm
J1: Buss; IDC-Header_2x04_P2.54mm_Vertical
J2: Control Signals; IDC-Header_2x06_P2.54mm_Vertical
J9: B-Register Out; IDC-Header_2x04_P2.54mm_Vertical
R1, R2, R3, R4, R5, R6, R7, R8, R9, R10, R11, R12, R13, R14, R15, R16, R17, R18, R19, R20, R21, R22, R23, R24, R25, R26, R27, R28, R29, R30, R31, R32: R; R_Axial_DIN0204_L3.6mm_D1.6mm_P7.62mm_Horizontal
U1, U3, U5, U6: 74LS377; DIP-20_W7.62mm
U2, U4, U7, U8: 74LS245; DIP-20_W7.62mm

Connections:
+5V: J2.12, U1.20 (VCC), U2.1 (A->B), U2.20 (VCC), U3.20 (VCC), U4.1 (A->B), U4.20 (VCC), U5.20 (VCC), U6.20 (VCC), U7.1 (A->B), U7.20 (VCC), U8.1 (A->B), U8.20 (VCC)
GND: J2.11, R1.2, R2.2, R3.2, R4.2, R5.2, R6.2, R7.2, R8.2, R9.2, R10.2, R11.2, R12.2, R13.2, R14.2, R15.2, R16.2, R17.2, R18.2, R19.2, R20.2, R21.2, R22.2, R23.2, R24.2, R25.2, R26.2, R27.2, R28.2, R29.2, R30.2, R31.2, R32.2, U1.10 (GND), U2.10 (GND), U3.10 (GND), U4.10 (GND), U5.10 (GND), U6.10 (GND), U7.10 (GND), U8.10 (GND)
unnamed: D0.1 (K), R1.1
unnamed: D0.2 (A), U1.2 (Q0), U2.2 (A0)
unnamed: D1.1 (K), R2.1
unnamed: D1.2 (A), U1.5 (Q1), U2.3 (A1)
unnamed: D2.1 (K), R3.1
unnamed: D2.2 (A), U1.6 (Q2), U2.4 (A2)
unnamed: D3.1 (K), R4.1
unnamed: D3.2 (A), U1.9 (Q3), U2.5 (A3)
unnamed: D4.1 (K), R5.1
unnamed: D4.2 (A), U1.12 (Q4), U2.6 (A4)
unnamed: D5.1 (K), R6.1
unnamed: D5.2 (A), U1.15 (Q5), U2.7 (A5)
unnamed: D6.1 (K), R7.1
unnamed: D6.2 (A), U1.16 (Q6), U2.8 (A6)
unnamed: D7.1 (K), R8.1
unnamed: D7.2 (A), U1.19 (Q7), U2.9 (A7)
unnamed: D8.1 (K), R9.1
unnamed: D8.2 (A), U3.2 (Q0), U4.2 (A0)
unnamed: D9.1 (K), R10.1
unnamed: D9.2 (A), U3.5 (Q1), U4.3 (A1)
unnamed: D10.1 (K), R11.1
unnamed: D10.2 (A), U3.6 (Q2), U4.4 (A2)
unnamed: D11.1 (K), R12.1
unnamed: D11.2 (A), U3.9 (Q3), U4.5 (A3)
unnamed: D12.1 (K), R13.1
unnamed: D12.2 (A), U3.12 (Q4), U4.6 (A4)
unnamed: D13.1 (K), R14.1
unnamed: D13.2 (A), U3.15 (Q5), U4.7 (A5)
unnamed: D14.1 (K), R15.1
unnamed: D14.2 (A), U3.16 (Q6), U4.8 (A6)
unnamed: D15.1 (K), R16.1
unnamed: D15.2 (A), U3.19 (Q7), U4.9 (A7)
unnamed: D16.1 (K), R17.1
unnamed: D16.2 (A), J9.8, U5.2 (Q0), U7.2 (A0)
unnamed: D17.1 (K), R18.1
unnamed: D17.2 (A), J9.7, U5.5 (Q1), U7.3 (A1)
unnamed: D18.1 (K), R19.1
unnamed: D18.2 (A), J9.6, U5.6 (Q2), U7.4 (A2)
unnamed: D19.1 (K), R20.1
unnamed: D19.2 (A), J9.5, U5.9 (Q3), U7.5 (A3)
unnamed: D20.1 (K), R21.1
unnamed: D20.2 (A), J9.4, U5.12 (Q4), U7.6 (A4)
unnamed: D21.1 (K), R22.1
unnamed: D21.2 (A), J9.3, U5.15 (Q5), U7.7 (A5)
unnamed: D22.1 (K), R23.1
unnamed: D22.2 (A), J9.2, U5.16 (Q6), U7.8 (A6)
unnamed: D23.1 (K), R24.1
unnamed: D23.2 (A), J9.1, U5.19 (Q7), U7.9 (A7)
unnamed: D24.1 (K), R25.1
unnamed: D24.2 (A), U6.2 (Q0), U8.2 (A0)
unnamed: D25.1 (K), R26.1
unnamed: D25.2 (A), U6.5 (Q1), U8.3 (A1)
unnamed: D26.1 (K), R27.1
unnamed: D26.2 (A), U6.6 (Q2), U8.4 (A2)
unnamed: D27.1 (K), R28.1
unnamed: D27.2 (A), U6.9 (Q3), U8.5 (A3)
unnamed: D28.1 (K), R29.1
unnamed: D28.2 (A), U6.12 (Q4), U8.6 (A4)
unnamed: D29.1 (K), R30.1
unnamed: D29.2 (A), U6.15 (Q5), U8.7 (A5)
unnamed: D30.1 (K), R31.1
unnamed: D30.2 (A), U6.16 (Q6), U8.8 (A6)
unnamed: D31.1 (K), R32.1
unnamed: D31.2 (A), U6.19 (Q7), U8.9 (A7)
unnamed: J1.1, U1.18 (D7), U2.11 (B7), U3.18 (D7), U4.11 (B7), U5.18 (D7), U6.18 (D7), U7.11 (B7), U8.11 (B7)
unnamed: J1.2, U1.17 (D6), U2.12 (B6), U3.17 (D6), U4.12 (B6), U5.17 (D6), U6.17 (D6), U7.12 (B6), U8.12 (B6)
unnamed: J1.3, U1.14 (D5), U2.13 (B5), U3.14 (D5), U4.13 (B5), U5.14 (D5), U6.14 (D5), U7.13 (B5), U8.13 (B5)
unnamed: J1.4, U1.13 (D4), U2.14 (B4), U3.13 (D4), U4.14 (B4), U5.13 (D4), U6.13 (D4), U7.14 (B4), U8.14 (B4)
unnamed: J1.5, U1.8 (D3), U2.15 (B3), U3.8 (D3), U4.15 (B3), U5.8 (D3), U6.8 (D3), U7.15 (B3), U8.15 (B3)
unnamed: J1.6, U1.7 (D2), U2.16 (B2), U3.7 (D2), U4.16 (B2), U5.7 (D2), U6.7 (D2), U7.16 (B2), U8.16 (B2)
unnamed: J1.7, U1.4 (D1), U2.17 (B1), U3.4 (D1), U4.17 (B1), U5.4 (D1), U6.4 (D1), U7.17 (B1), U8.17 (B1)
unnamed: J1.8, U1.3 (D0), U2.18 (B0), U3.3 (D0), U4.18 (B0), U5.3 (D0), U6.3 (D0), U7.18 (B0), U8.18 (B0)
unnamed: J2.1, U1.11 (CP), U3.11 (CP), U5.11 (CP), U6.11 (CP)
unnamed: J2.2, U1.1 (~E)
unnamed: J2.3, U2.19 (CE)
unnamed: J2.4, U5.1 (~E)
unnamed: J2.5, U7.19 (CE)
unnamed: J2.6, U3.1 (~E)
unnamed: J2.7, U4.19 (CE)
unnamed: J2.8, U6.1 (~E)
unnamed: J2.9, U8.19 (CE)

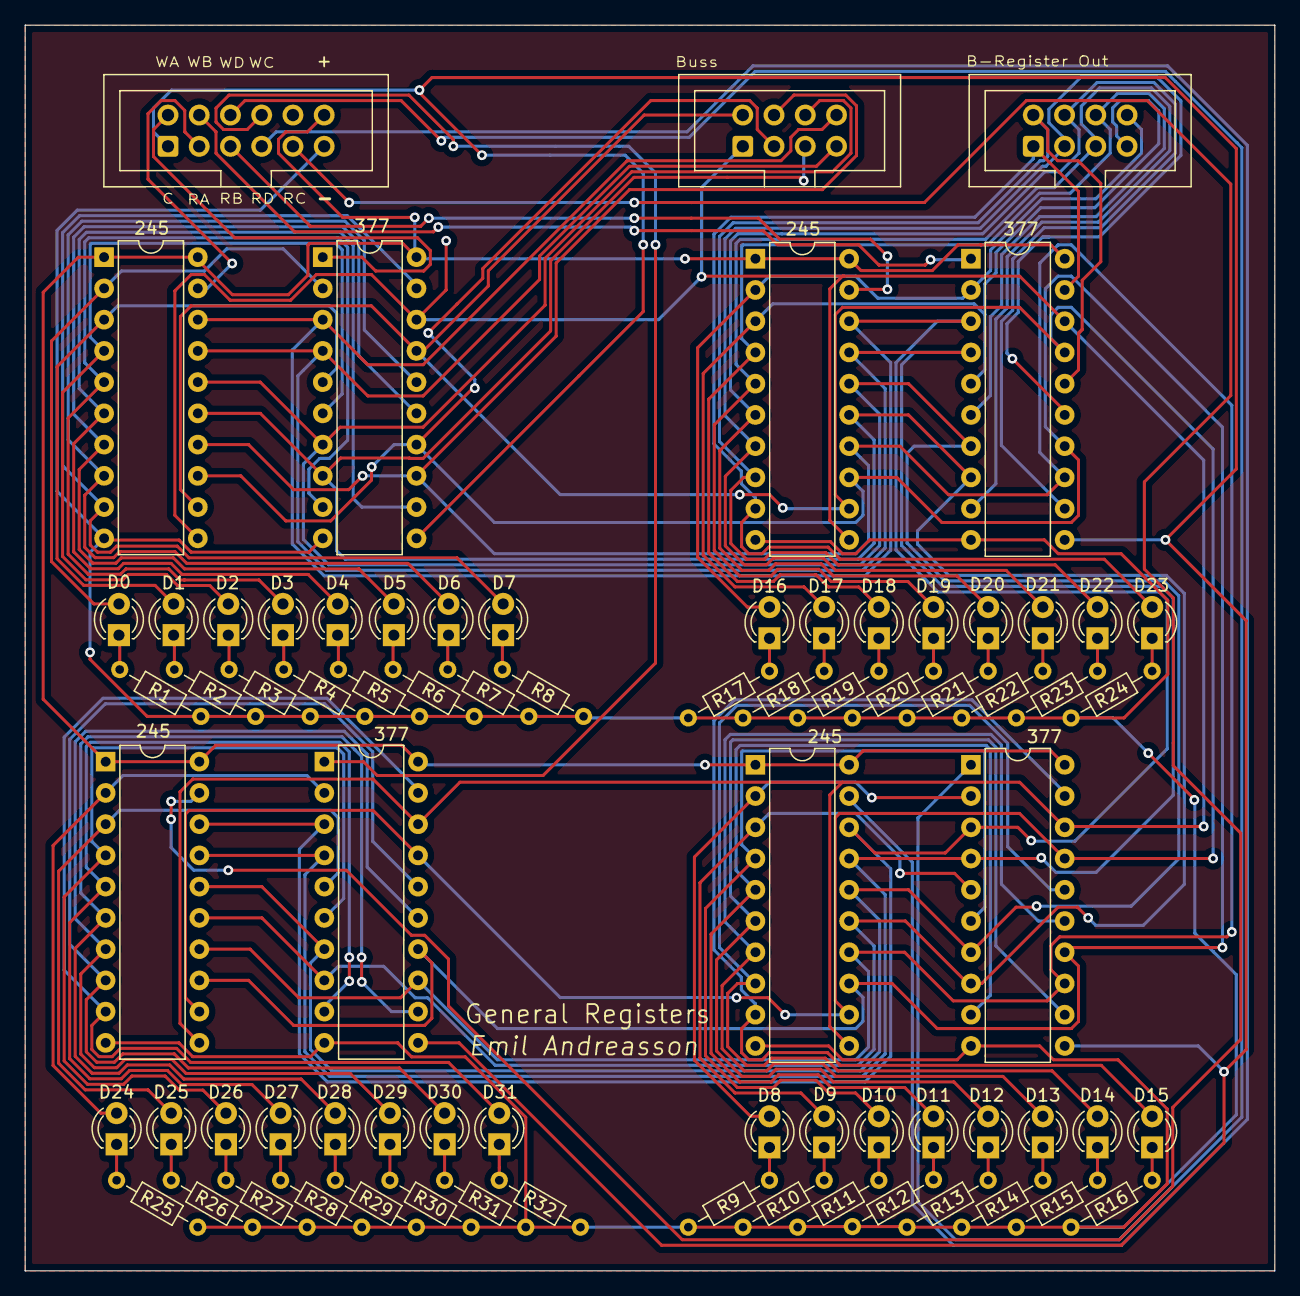
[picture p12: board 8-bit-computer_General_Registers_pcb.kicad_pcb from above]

Board: 2 copper layers, 101.6 x 101.3 mm, 75 parts (0 on the bottom side), 83 nets.

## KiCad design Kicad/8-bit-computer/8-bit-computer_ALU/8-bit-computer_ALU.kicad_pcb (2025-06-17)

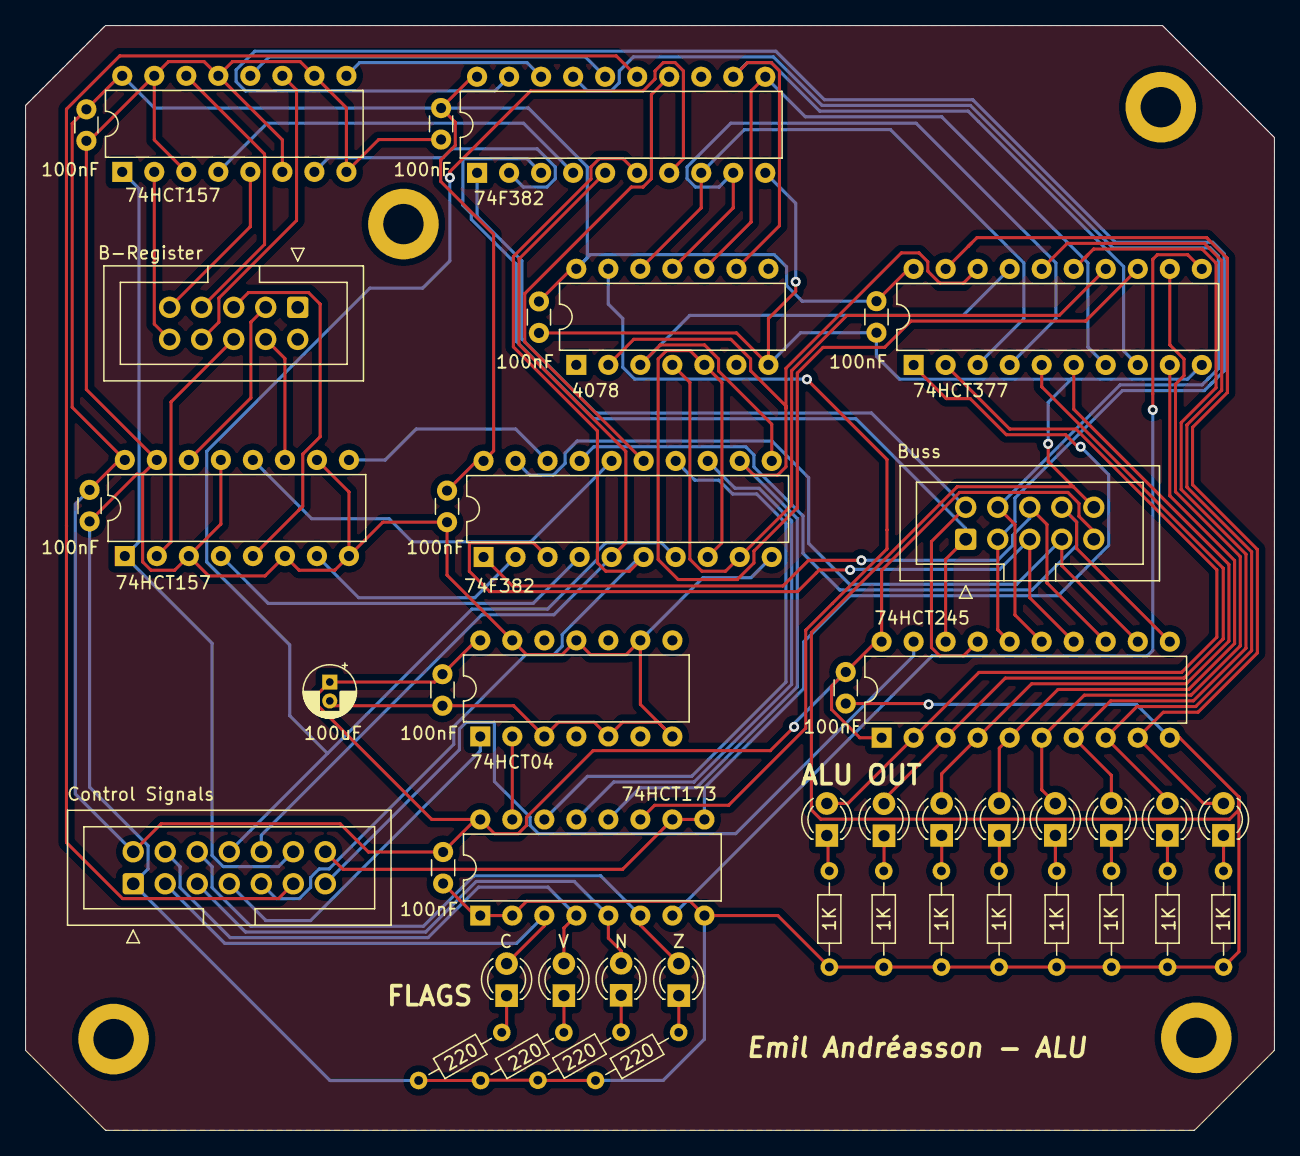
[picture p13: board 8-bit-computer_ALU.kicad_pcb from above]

Board: 2 copper layers, 99.1 x 87.6 mm, 50 parts (0 on the bottom side), 72 nets.

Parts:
C1: 100uF; CP_Radial_D4.0mm_P1.50mm
C2, C3, C4, C5, C6, C7, C8, C9, C10: 100nF; C_Disc_D3.0mm_W1.6mm_P2.50mm
C11: C; LED_D3.0mm
D1, D2, D3, D4, D5, D6, D7, D8: LED; LED_D3.0mm
H1, H2, H3, H4: MountingHole; MountingHole_3.2mm_M3_DIN965_Pad
J1: Control Signals; IDC-Header_2x07_P2.54mm_Vertical
J2: B-Register; IDC-Header_2x05_P2.54mm_Vertical
J3: Buss; IDC-Header_2x05_P2.54mm_Vertical
N1: N; LED_D3.0mm
R1, R2, R3, R4, R5, R6, R7, R8: 1K; R_Axial_DIN0204_L3.6mm_D1.6mm_P7.62mm_Horizontal
R9, R10, R11, R12: 220; R_Axial_DIN0204_L3.6mm_D1.6mm_P7.62mm_Horizontal
U1: 74HCT04; DIP-14_W7.62mm
U3: 74HCT377; DIP-20_W7.62mm
U4, U5: 74HCT157; DIP-16_W7.62mm
U6: 74HCT245; DIP-20_W7.62mm
U7, U8: 74F382; DIP-20_W7.62mm
U9: 4078; DIP-14_W7.62mm
U10: 74HCT173; DIP-16_W7.62mm
V1: V; LED_D3.0mm
Z1: Z; LED_D3.0mm

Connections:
+5V: C1.1, C2.1, C3.1, C4.1, C5.1, C6.1, C7.1, C8.1, C9.1, C10.1, J1.2, J3.9, U1.14 (VCC), U3.20 (VCC), U4.16 (VCC), U5.16 (VCC), U6.1 (A->B), U6.20 (VCC), U7.20 (5V), U8.20 (5V), U9.14 (Vdd), U10.16 (VCC)
/C: C11.2 (A), J1.3, U10.3 (Q0)
/N: J1.5, N1.2 (A), U10.5 (Q2)
/V: J1.4, U10.4 (Q1), V1.2 (A)
/Z: J1.6, U10.6 (Q3), Z1.2 (A)
GND: C1.2, C2.2, C3.2, C4.2, C5.2, C6.2, C7.2, C8.2, C9.2, C10.2, J1.1, J3.10, R1.1, R2.1, R3.1, R4.1, R5.1, R6.1, R7.1, R8.1, R9.1, R10.1, R11.1, R12.1, U1.3, U1.5, U1.7 (GND), U1.9, U1.11, U1.13, U3.10 (GND), U4.3 (I1a), U4.6 (I1b), U4.8 (GND), U4.10 (I1c), U4.13 (I1d), U4.15 (E), U5.3 (I1a), U5.6 (I1b), U5.8 (GND), U5.10 (I1c), U5.13 (I1d), U5.15 (E), U6.10 (GND), U7.10 (Gnd), U8.10 (Gnd), U9.7 (Vss), U10.1 (Oe1), U10.2 (Oe2), U10.8 (GND)
unnamed: C11.1 (K), R9.2
unnamed: D1.2 (A), U3.2 (Q0), U6.2 (A0)
unnamed: D1.1 (K), R1.2
unnamed: D2.2 (A), U3.5 (Q1), U6.3 (A1)
unnamed: D2.1 (K), R2.2
unnamed: D3.2 (A), U3.6 (Q2), U6.4 (A2)
unnamed: D3.1 (K), R3.2
unnamed: D4.2 (A), U3.9 (Q3), U6.5 (A3)
unnamed: D4.1 (K), R4.2
unnamed: D5.2 (A), U3.12 (Q4), U6.6 (A4)
unnamed: D5.1 (K), R5.2
unnamed: D6.2 (A), U3.15 (Q5), U6.7 (A5)
unnamed: D6.1 (K), R6.2
unnamed: D7.2 (A), U3.16 (Q6), U6.8 (A6)
unnamed: D7.1 (K), R7.2
unnamed: D8.2 (A), U3.19 (Q7), U6.9 (A7)
unnamed: D8.1 (K), R8.2
unnamed: J1.7, U1.1
unnamed: J1.8, U7.7 (S2), U8.7 (S2)
unnamed: J1.9, U7.6 (S1), U8.6 (S1)
unnamed: J1.10, U7.5 (S0), U8.5 (S0)
unnamed: J1.11, U8.15 (Cn)
unnamed: J1.12, U4.1 (S), U5.1 (S)
unnamed: J1.13, U6.19 (CE)
unnamed: J1.14, U3.1 (~E), U10.9 (E1), U10.10 (E2)
unnamed: J2.3, U5.14 (I0d)
unnamed: J2.4, U5.11 (I0c)
unnamed: J2.5, U5.5 (I0b)
unnamed: J2.6, U5.2 (I0a)
unnamed: J2.7, U4.14 (I0d)
unnamed: J2.8, U4.11 (I0c)
unnamed: J2.9, U4.5 (I0b)
unnamed: J2.10, U4.2 (I0a)
unnamed: J3.1, U6.18 (B0), U8.3 (A0)
unnamed: J3.2, U6.17 (B1), U8.1 (A1)
unnamed: J3.3, U6.16 (B2), U8.19 (A2)
unnamed: J3.4, U6.15 (B3), U8.17 (A3)
unnamed: J3.5, U6.14 (B4), U7.3 (A0)
unnamed: J3.6, U6.13 (B5), U7.1 (A1)
unnamed: J3.7, U6.12 (B6), U7.19 (A2)
unnamed: J3.8, U6.11 (B7), U7.17 (A3)
unnamed: N1.1 (K), R11.2
unnamed: U3.3 (D0), U8.8 (F0), U9.12
unnamed: U3.4 (D1), U8.9 (F1), U9.11
unnamed: U3.7 (D2), U8.11 (F2), U9.10
unnamed: U3.8 (D3), U8.12 (F3), U9.9
unnamed: U3.13 (D4), U7.8 (F0), U9.5
unnamed: U3.14 (D5), U7.9 (F1), U9.4
unnamed: U3.17 (D6), U7.11 (F2), U9.3
unnamed: U4.4 (Za), U8.4 (B0)
unnamed: U4.7 (Zb), U8.2 (B1)
unnamed: U4.9 (Zc), U8.18 (B2)
unnamed: U4.12 (Zd), U8.16 (B3)
unnamed: U5.4 (Za), U7.4 (B0)
unnamed: U5.7 (Zb), U7.2 (B1)
unnamed: U5.9 (Zc), U7.18 (B2)
unnamed: U5.12 (Zd), U7.16 (B3)
unnamed: U7.15 (Cn), U8.14 (Cn+4)
unnamed: U3.11 (CP), U10.7 (Cp)
unnamed: U7.14 (Cn+4), U10.14 (D0)
unnamed: U7.13 (OVR), U10.13 (D1)
unnamed: U3.18 (D7), U7.12 (F3), U9.2, U10.12 (D2)
unnamed: U9.13, U10.11 (D3)
unnamed: U1.2, U10.15 (Mr)
unnamed: R10.2, V1.1 (K)
unnamed: R12.2, Z1.1 (K)

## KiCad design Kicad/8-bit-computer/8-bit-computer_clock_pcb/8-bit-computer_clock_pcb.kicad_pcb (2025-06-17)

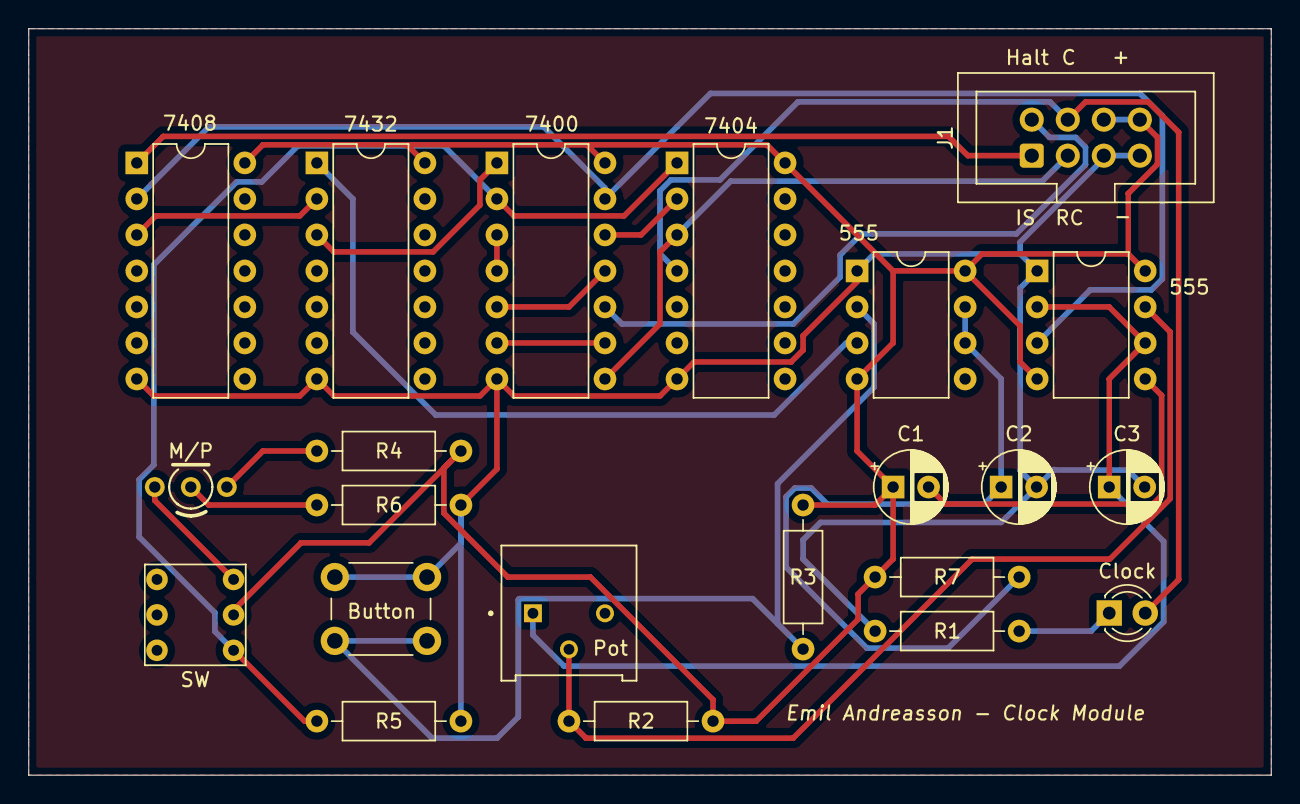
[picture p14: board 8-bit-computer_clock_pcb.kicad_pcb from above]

Board: 2 copper layers, 87.6 x 52.6 mm, 22 parts (0 on the bottom side), 24 nets.

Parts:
555, 555#2: NE555P; DIP-8_W7.62mm
7400: 74HCT00; DIP-14_W7.62mm
7404: 74HCT04; DIP-14_W7.62mm
7408: 74HCT08; DIP-14_W7.62mm
7432: 74HCT32; DIP-14_W7.62mm
Button: manual clock; SW_PUSH_6mm
C1: 0.1u; CP_Radial_D5.0mm_P2.50mm
C2, C3: 100u; CP_Radial_D5.0mm_P2.50mm
Clock: Clock; LED_D3.0mm_IRBlack
J1: Conn_01x08_Female; IDC-Header_2x04_P2.54mm_Vertical
M/P: L-115WEGW-CA; DUOLED-A-3MM
Pot: R_POT; TRIM_3386P-1-101T
R1: 1.47k; R_Axial_DIN0207_L6.3mm_D2.5mm_P10.16mm_Horizontal
R2: 1k; R_Axial_DIN0207_L6.3mm_D2.5mm_P10.16mm_Horizontal
R3, R5: 100k; R_Axial_DIN0207_L6.3mm_D2.5mm_P10.16mm_Horizontal
R4: 100; R_Axial_DIN0207_L6.3mm_D2.5mm_P10.16mm_Horizontal
R6, R7: 470; R_Axial_DIN0207_L6.3mm_D2.5mm_P10.16mm_Horizontal
SW: SW_SPDT; Switch_on_off

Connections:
+5V: 555.4, 555.8, 555#2.4, 555#2.8, 7400.14, 7404.14, 7408.14, 7432.14, C1.1, J1.6, J1.8, R1.2, R2.2, R3.2, R4.2, SW.2
GND: 555.1, 555#2.1, 7400.7, 7404.7, 7408.7, 7432.7, Button.1, C2.2, C3.2, J1.5, J1.7, R5.2, R6.1, R7.1
unnamed: 555#2.2, Button.2, R3.1
unnamed: 555.5, C1.2
unnamed: 555#2.6, 555#2.7, C2.1, R1.1
unnamed: 555.2, 555.6, C3.1, Pot.1
unnamed: Clock.1, R7.2
unnamed: 7404.4, Clock.2, J1.4
unnamed: 7408.1, J1.1
unnamed: 7400.10, J1.2
unnamed: 7400.8, 7404.3, J1.3
unnamed: M/P.1, SW.1
unnamed: M/P.2, R6.2
unnamed: M/P.3, R4.1
unnamed: 555.7, Pot.2, R2.1
unnamed: 7400.2, 7404.1, R5.1, SW.3
unnamed: 555.3, 7400.13, 7408.2
unnamed: 555#2.3, 7432.1
unnamed: 7408.3, 7432.2
unnamed: 7400.1, 7432.3
unnamed: 7400.3, 7400.4
unnamed: 7400.6, 7400.9
unnamed: 7400.5, 7400.11
unnamed: 7400.12, 7404.2

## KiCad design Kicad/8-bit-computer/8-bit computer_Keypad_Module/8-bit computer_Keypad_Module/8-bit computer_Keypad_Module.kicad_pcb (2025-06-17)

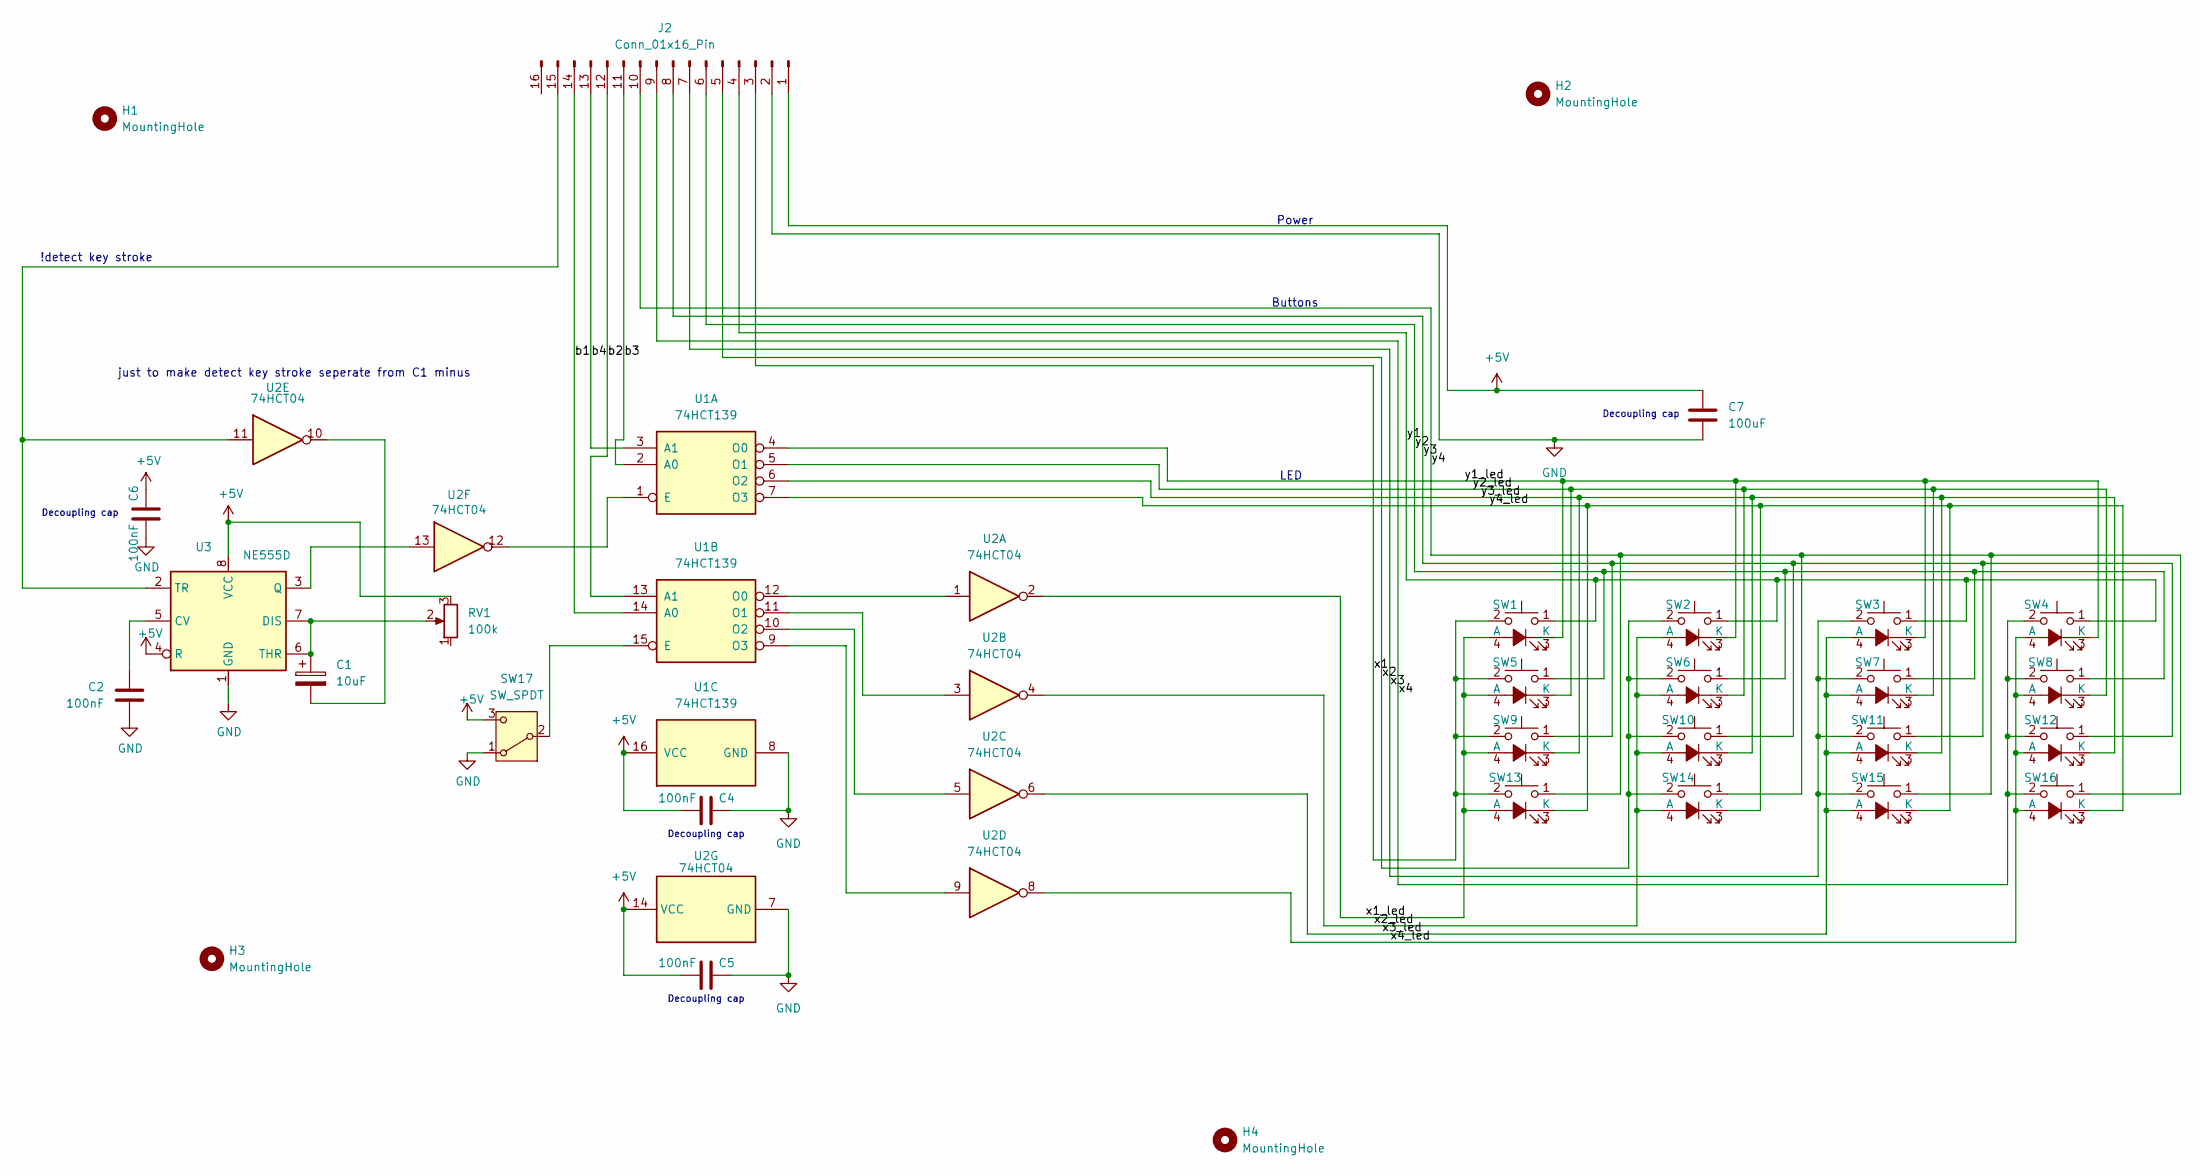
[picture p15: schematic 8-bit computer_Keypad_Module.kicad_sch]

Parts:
C1: 10uF; CP_Radial_D5.0mm_P2.00mm
C2: 100nF; CP_Radial_D5.0mm_P2.00mm
C4, C5, C6: 100nF; C_Disc_D3.0mm_W1.6mm_P2.50mm
C7: 100uF; CP_Radial_D4.0mm_P1.50mm
H1, H2, H3, H4: MountingHole; MountingHole_3.2mm_M3_DIN965_Pad
J2: Conn_01x16_Pin; IDC-Header_2x08_P2.54mm_Vertical
RV1: 100k; Potentiometer_Bourns_3296W_Vertical
SW1, SW2, SW3, SW4, SW5, SW6, SW7, SW8, SW9, SW10, SW11, SW12, SW13, SW14, SW15, SW16: CherryMX_LED; CherryMX_1.00u_LED
SW17: SW_SPDT; hole for bistable switch
U1: 74HCT139; DIP-16_W7.62mm
U2: 74HCT04; DIP-14_W7.62mm
U3: NE555D; DIP-8_W7.62mm

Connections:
+5V: C4.1, C5.1, C6.2, C7.2, J2.1, RV1.3, SW17.3 (C), U1.16 (VCC), U2.14 (VCC), U3.4 (R), U3.8 (VCC)
/b1: J2.14, U1.14 (A0)
/b2: J2.12, U1.13 (A1)
/b3: J2.11, U1.2 (A0)
/b4: J2.13, U1.3 (A1)
/x1: J2.3, SW1.2, SW5.2, SW9.2, SW13.2
/x1_led: SW1.4 (A), SW5.4 (A), SW9.4 (A), SW13.4 (A), U2.2
/x2: J2.5, SW2.2, SW6.2, SW10.2, SW14.2
/x2_led: SW2.4 (A), SW6.4 (A), SW10.4 (A), SW14.4 (A), U2.4
/x3: J2.7, SW3.2, SW7.2, SW11.2, SW15.2
/x3_led: SW3.4 (A), SW7.4 (A), SW11.4 (A), SW15.4 (A), U2.6
/x4: J2.9, SW4.2, SW8.2, SW12.2, SW16.2
/x4_led: SW4.4 (A), SW8.4 (A), SW12.4 (A), SW16.4 (A), U2.8
/y1: J2.4, SW1.1, SW2.1, SW3.1, SW4.1
/y1_led: SW1.3 (K), SW2.3 (K), SW3.3 (K), SW4.3 (K), U1.4 (O0)
/y2: J2.6, SW5.1, SW6.1, SW7.1, SW8.1
/y2_led: SW5.3 (K), SW6.3 (K), SW7.3 (K), SW8.3 (K), U1.5 (O1)
/y3: J2.8, SW9.1, SW10.1, SW11.1, SW12.1
/y3_led: SW9.3 (K), SW10.3 (K), SW11.3 (K), SW12.3 (K), U1.6 (O2)
/y4: J2.10, SW13.1, SW14.1, SW15.1, SW16.1
/y4_led: SW13.3 (K), SW14.3 (K), SW15.3 (K), SW16.3 (K), U1.7 (O3)
GND: C2.1, C4.2, C5.2, C6.1, C7.1, J2.2, SW17.1 (A), U1.8 (GND), U2.7 (GND), U3.1 (GND)
unnamed: C1.2, U2.10
unnamed: J2.15, U2.11, U3.2 (TR)
unnamed: SW17.2 (B), U1.15 (E)
unnamed: U1.1 (E), U2.12
unnamed: U1.12 (O0), U2.1
unnamed: U1.11 (O1), U2.3
unnamed: U1.10 (O2), U2.5
unnamed: U1.9 (O3), U2.9
unnamed: C2.2, U3.5 (CV)
unnamed: C1.1, RV1.2, U3.6 (THR), U3.7 (DIS)
unnamed: U2.13, U3.3 (Q)

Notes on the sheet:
Decoupling cap
Power
Buttons
just to make detect key stroke seperate from C1 minus
!detect key stroke
LED

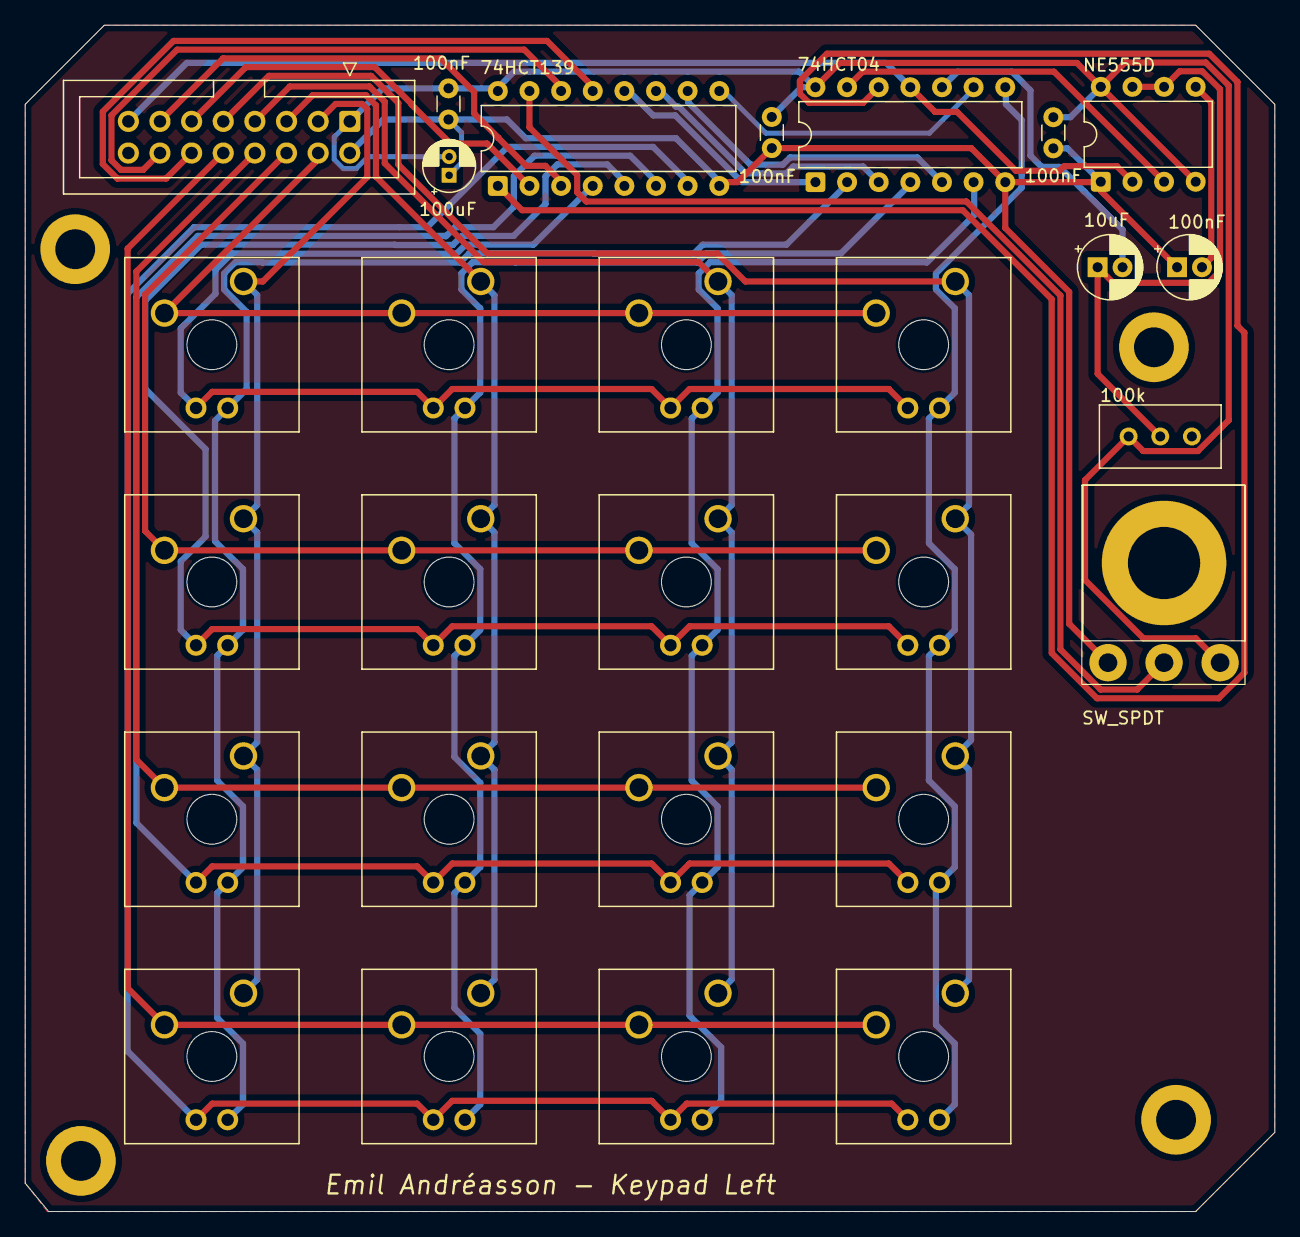
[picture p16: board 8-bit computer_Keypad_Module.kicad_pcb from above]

Board: 2 copper layers, 100.3 x 95.2 mm, 32 parts (0 on the bottom side), 33 nets.

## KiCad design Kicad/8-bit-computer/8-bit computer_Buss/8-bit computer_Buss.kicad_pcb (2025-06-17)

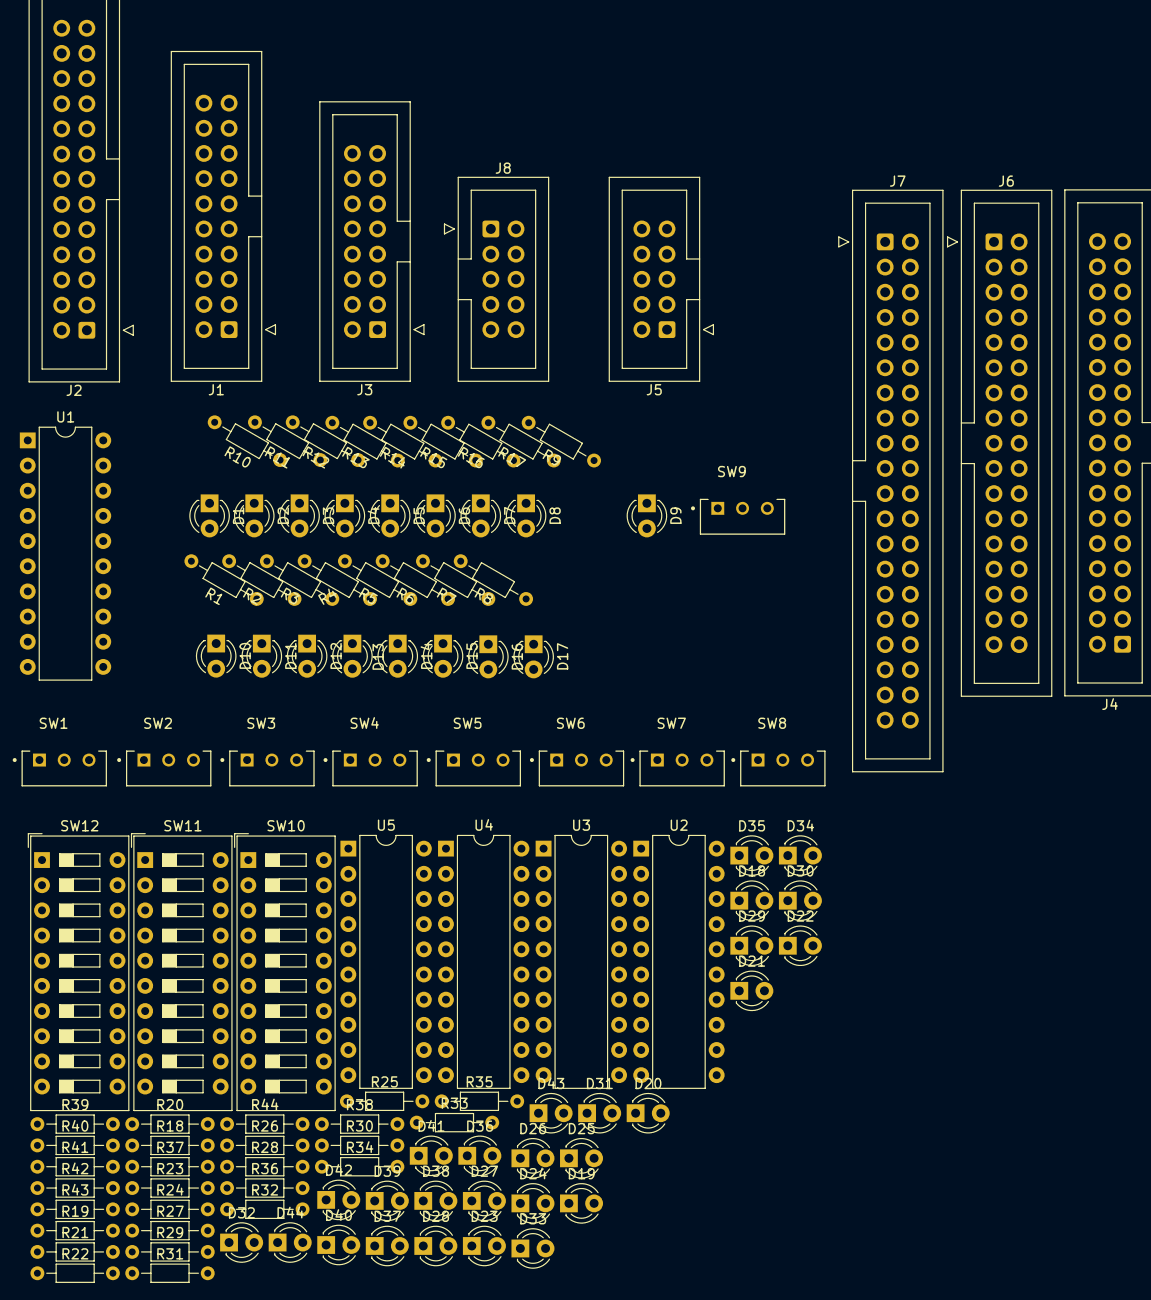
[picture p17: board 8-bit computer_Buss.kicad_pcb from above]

Board: 2 copper layers, 113 parts (0 on the bottom side), 65 nets, no tracks yet.

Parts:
D1, D2, D3, D4, D5, D6, D7, D8, D9, D10, D11, D12, D13, D14, D15, D16, D17, D18, D19, D20, D21, D22, D23, D24, D25, D26, D27, D28, D29, D30, D31, D32, D33, D34, D35, D36, D37, D38, D39, D40, D41, D42, D43, D44: LED; LED_D3.0mm
J1: General Registers; IDC-Header_2x10_P2.54mm_Vertical
J2: ALU; IDC-Header_2x13_P2.54mm_Vertical
J3: PC and Stack pointer register; IDC-Header_2x08_P2.54mm_Vertical
J4: RAM; IDC-Header_2x17_P2.54mm_Vertical
J5: Bot Loader; IDC-Header_2x05_P2.54mm_Vertical
J6: Input module; IDC-Header_2x17_P2.54mm_Vertical
J7: Control Matrix; IDC-Header_2x20_P2.54mm_Vertical
J8: Clock; IDC-Header_2x05_P2.54mm_Vertical
R1, R2, R3, R10, R11, R12, R13, R14, R15, R16, R17, R18, R19, R20, R26, R27, R28, R34, R35, R36: 1000; R_Axial_DIN0204_L3.6mm_D1.6mm_P7.62mm_Horizontal
R4, R5, R6, R7, R8, R21, R22, R23, R24, R25, R29, R30, R31, R32, R33, R37, R38, R39, R40, R41, R42, R43, R44: R; R_Axial_DIN0204_L3.6mm_D1.6mm_P7.62mm_Horizontal
R9: 470; R_Axial_DIN0204_L3.6mm_D1.6mm_P7.62mm_Horizontal
SW1, SW2, SW3, SW4, SW5, SW6, SW7, SW8, SW9: SW_DIP_x01; SW_EG1270
SW10, SW11, SW12: SW_DIP_x10; SW_DIP_SPSTx10_Slide_9.78x27.58mm_W7.62mm_P2.54mm
U1, U2, U3, U4, U5: 74LS245; DIP-20_W7.62mm

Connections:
+5V: D9.2, SW1.1, SW2.1, SW3.1, SW4.1, SW5.1, SW6.1, SW7.1, SW8.1, U1.1
GND: R1.2, R2.2, R3.2, R4.2, R5.2, R6.2, R7.2, R8.2, R10.2, R11.2, R12.2, R13.2, R14.2, R15.2, R16.2, R17.2, SW9.1, U1.10
unnamed: D1.1, R10.1
unnamed: D2.1, R11.1
unnamed: D3.1, R12.1
unnamed: D4.1, R13.1
unnamed: D5.1, R14.1
unnamed: D6.1, R15.1
unnamed: D7.1, R16.1
unnamed: D8.1, R17.1
unnamed: D9.1, R9.1
unnamed: D10.1, R1.1
unnamed: D10.2, SW4.2, U1.2
unnamed: D11.1, R2.1
unnamed: D11.2, SW5.2, U1.3
unnamed: D12.1, R3.1
unnamed: D12.2, SW6.2, U1.4
unnamed: D13.1, R4.1
unnamed: D13.2, SW7.2, U1.5
unnamed: D14.1, R5.1
unnamed: D14.2, SW8.2, U1.6
unnamed: D15.1, R6.1
unnamed: D15.2, SW1.2, U1.7
unnamed: D16.1, R7.1
unnamed: D16.2, SW2.2, U1.8
unnamed: D17.1, R8.1
unnamed: D17.2, SW3.2, U1.9
unnamed: D18.1, R18.1
unnamed: D19.1, R19.1
unnamed: D20.1, R20.1
unnamed: D21.1, R21.1
unnamed: D22.1, R22.1
unnamed: D23.1, R23.1
unnamed: D24.1, R24.1
unnamed: D25.1, R25.1
unnamed: D26.1, R26.1
unnamed: D27.1, R27.1
unnamed: D28.1, R28.1
unnamed: D29.1, R29.1
unnamed: D30.1, R30.1
unnamed: D31.1, R31.1
unnamed: D32.1, R32.1
unnamed: D33.1, R33.1
unnamed: D34.1, R34.1
unnamed: D35.1, R35.1
unnamed: D36.1, R36.1
unnamed: D37.1, R37.1
unnamed: D38.1, R38.1
unnamed: D39.1, R39.1
unnamed: D40.1, R40.1
unnamed: D41.1, R41.1
unnamed: D42.1, R42.1
unnamed: D43.1, R43.1
unnamed: D44.1, R44.1
unnamed: J1.1, J2.1, J3.1, U1.18
unnamed: J1.2, J2.2, J3.2, U1.17
unnamed: J1.3, J2.3, J3.3, U1.16
unnamed: J1.4, J2.4, J3.4, U1.15
unnamed: J1.5, J2.5, J3.5, U1.14
unnamed: J1.6, J2.6, J3.6, U1.13
unnamed: J1.7, J2.7, U1.12
unnamed: J1.8, J2.8, U1.11
unnamed: R9.2, SW9.2, U1.19
unnamed: R18.2, R19.2, R20.2, R21.2, R22.2, R23.2, R24.2, R25.2, R26.2, R27.2, R28.2, R29.2, R30.2, R31.2, R32.2, R33.2, R34.2, R35.2, R36.2, R37.2, R38.2, R39.2, R40.2, R41.2, R42.2, R43.2, R44.2
unnamed: SW10.1, SW10.2, SW10.3, SW10.4, SW10.5, SW10.6, SW10.7, SW10.8, SW10.9, SW10.10, SW11.1, SW11.2, SW11.3, SW11.4, SW11.5, SW11.6, SW11.7, SW11.8, SW11.9, SW11.10, SW12.1, SW12.2, SW12.3, SW12.4, SW12.5, SW12.6, SW12.7, SW12.8, SW12.9, SW12.10

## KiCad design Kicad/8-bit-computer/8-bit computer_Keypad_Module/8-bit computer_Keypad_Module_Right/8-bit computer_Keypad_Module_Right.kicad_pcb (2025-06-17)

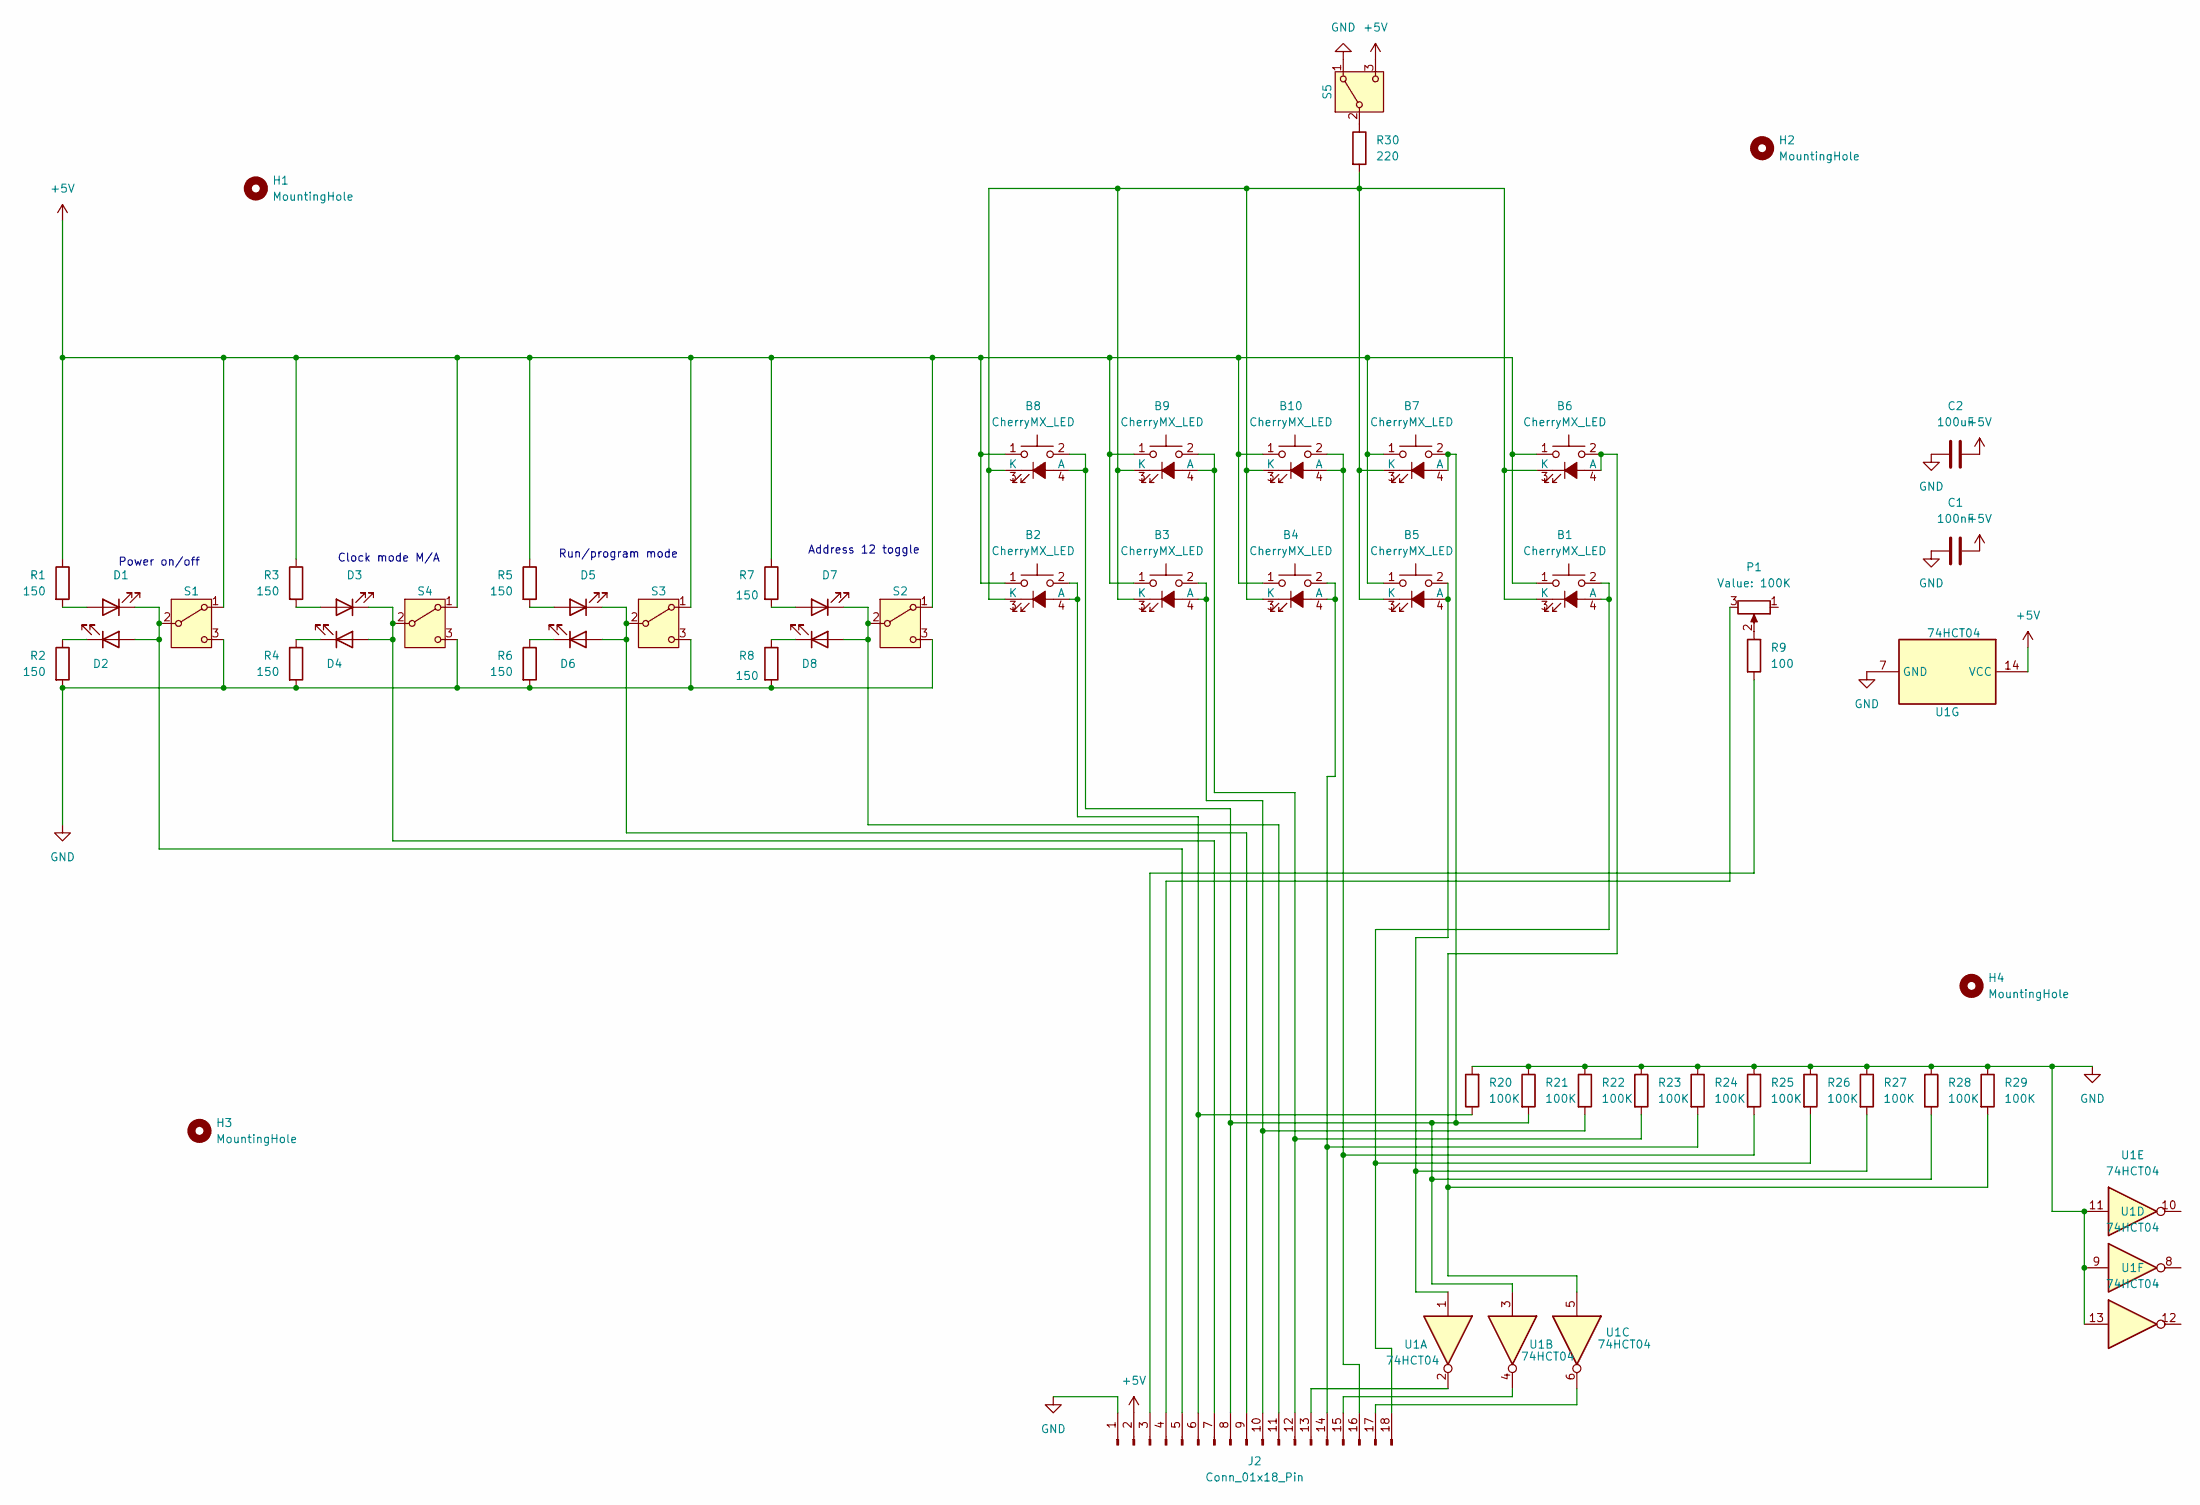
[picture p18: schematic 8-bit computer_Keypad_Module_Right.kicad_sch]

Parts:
B1, B2, B3, B4, B5, B6, B7, B8, B9, B10: CherryMX_LED; CherryMX_1.00u_LED
C1: 100nF; C_Disc_D3.0mm_W1.6mm_P2.50mm
C2: 100uF; CP_Radial_D4.0mm_P2.00mm
D1, D2, D3, D4, D5, D6, D7, D8: LED; LED_D3.0mm
H1, H2, H3, H4: MountingHole; MountingHole_3.2mm_M3_DIN965_Pad
J2: Conn_01x18_Pin; IDC-Header_2x09_P2.54mm_Vertical
P1: 100K; hole for potentiometer
R1, R2, R3, R4, R5, R6, R7, R8: 150; R_Axial_DIN0207_L6.3mm_D2.5mm_P10.16mm_Horizontal
R9: 100; R_Axial_DIN0207_L6.3mm_D2.5mm_P10.16mm_Horizontal
R20, R21, R22, R23, R24, R25, R26, R27, R28, R29: 100K; R_Axial_DIN0207_L6.3mm_D2.5mm_P10.16mm_Horizontal
R30: 220; R_Axial_DIN0207_L6.3mm_D2.5mm_P10.16mm_Horizontal
S1, S2, S3, S4, S5: SW_SPDT; hole for bistable switch
U1: 74HCT04; DIP-14_W7.62mm

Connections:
+5V: B1.1, B2.1, B3.1, B4.1, B5.1, B6.1, B7.1, B8.1, B9.1, B10.1, C1.1, C2.1, J2.2, R1.1, R3.1, R5.1, R7.1, S1.1 (A), S2.1 (A), S3.1 (A), S4.1 (A), S5.3 (C), U1.14 (VCC)
GND: C1.2, C2.2, J2.1, R2.2, R4.2, R6.2, R8.2, R20.2, R21.1, R22.1, R23.1, R24.1, R25.1, R26.1, R27.1, R28.1, R29.1, S1.3 (C), S2.3 (C), S3.3 (C), S4.3 (C), S5.1 (A), U1.7 (GND), U1.9, U1.11, U1.13
unnamed: B1.2, B1.4 (A), J2.18, R26.2
unnamed: B1.3 (K), B2.3 (K), B3.3 (K), B4.3 (K), B5.3 (K), B6.3 (K), B7.3 (K), B8.3 (K), B9.3 (K), B10.3 (K), R30.2
unnamed: B2.2, B2.4 (A), J2.6, R20.1
unnamed: B3.2, B3.4 (A), J2.10, R22.2
unnamed: B4.2, B4.4 (A), J2.14, R24.2
unnamed: B5.2, B5.4 (A), R27.2, U1.1
unnamed: B6.2, B6.4 (A), R29.2, U1.5
unnamed: B7.2, B7.4 (A), B8.2, B8.4 (A), J2.8, R21.2, R28.2, U1.3
unnamed: B9.2, B9.4 (A), J2.12, R23.2
unnamed: B10.2, B10.4 (A), J2.16, R25.2
unnamed: D1.2 (A), R1.2
unnamed: D1.1 (K), D2.2 (A), J2.5, S1.2 (B)
unnamed: D2.1 (K), R2.1
unnamed: D3.2 (A), R3.2
unnamed: D3.1 (K), D4.2 (A), J2.7, S4.2 (B)
unnamed: D4.1 (K), R4.1
unnamed: D5.2 (A), R5.2
unnamed: D5.1 (K), D6.2 (A), J2.9, S3.2 (B)
unnamed: D6.1 (K), R6.1
unnamed: D7.2 (A), R7.2
unnamed: D7.1 (K), D8.2 (A), J2.11, S2.2 (B)
unnamed: D8.1 (K), R8.1
unnamed: J2.3, R9.2
unnamed: J2.4, P1.3
unnamed: J2.13, U1.2
unnamed: J2.15, U1.4
unnamed: J2.17, U1.6
unnamed: P1.2, R9.1
unnamed: R30.1, S5.2 (B)

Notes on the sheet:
Run/program mode
Power on/off
Address 12 toggle
Clock mode M/A

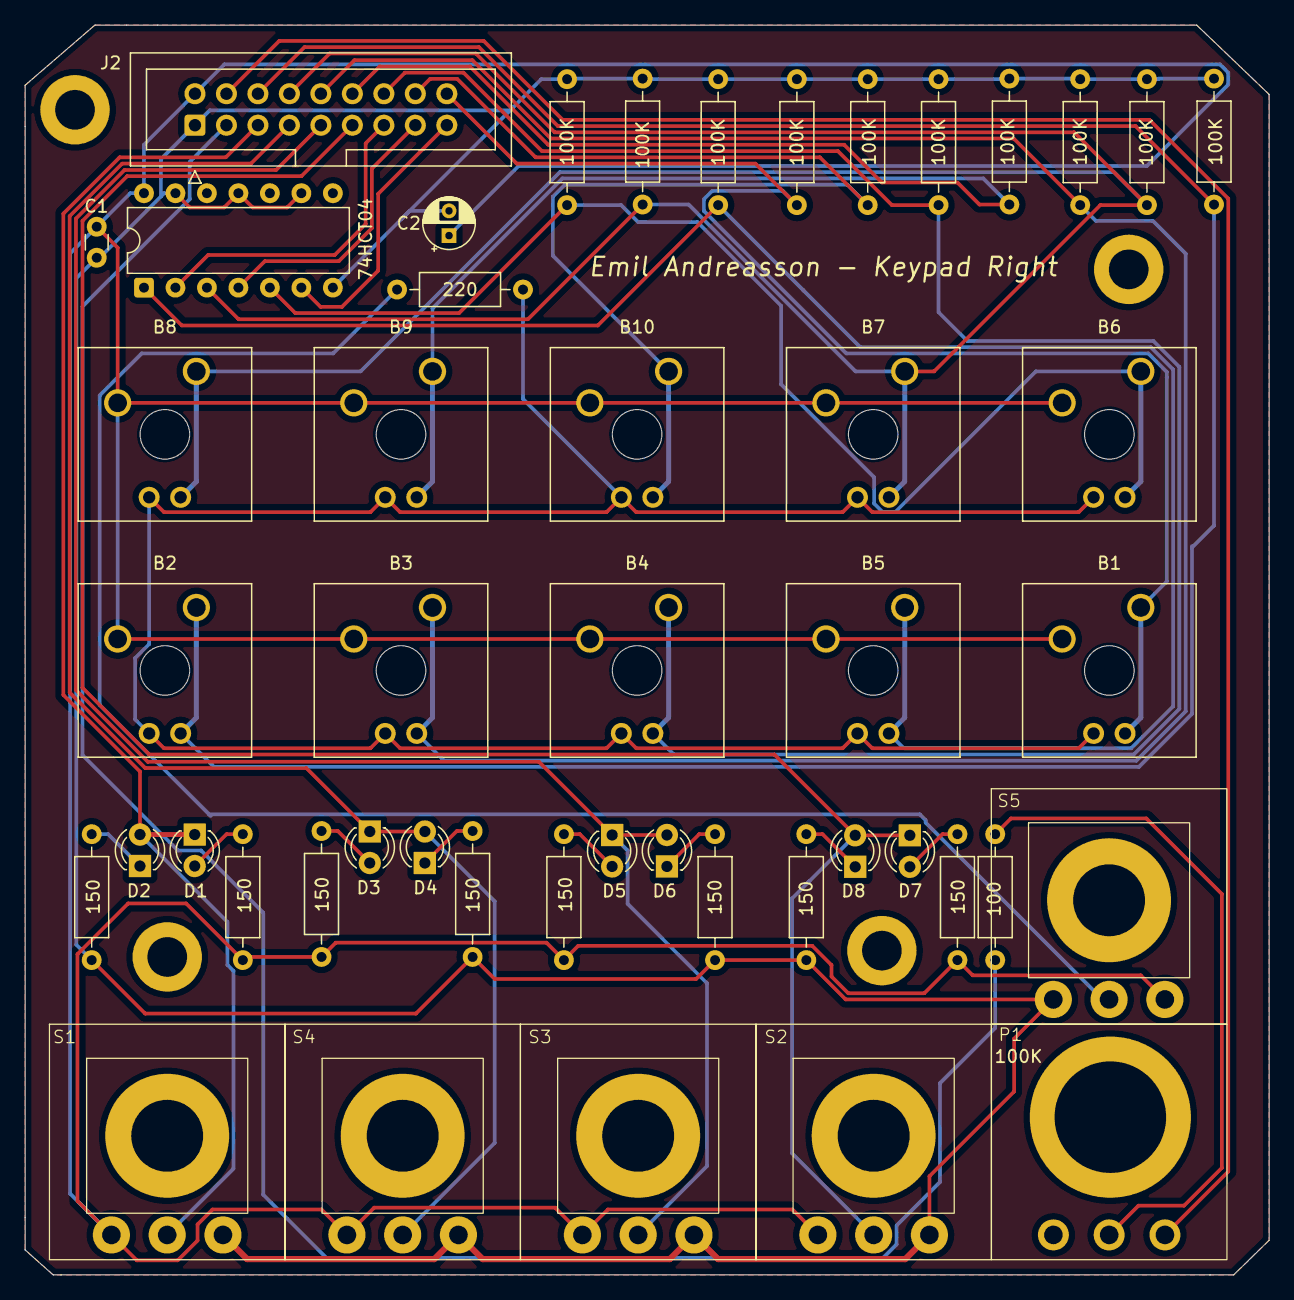
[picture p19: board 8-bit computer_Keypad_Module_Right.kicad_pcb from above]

Board: 2 copper layers, 100.4 x 100.8 mm, 52 parts (0 on the bottom side), 31 nets.

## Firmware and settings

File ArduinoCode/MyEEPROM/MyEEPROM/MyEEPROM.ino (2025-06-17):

#EEPROM programmer for green stone new 8-bit computer, James Bates version copy paste
#define ROM_NO 3

//#define INS_MOV 1
//#define INS_LOD 1
//#define INS_STO 1
#define INS_ALU 1

//#define DUMP 1

//#define CHECK_COVERAGE 1


#include <MyEEPROM.h>
#include <stdint.h>


/* signal word: bit position  31     30     29     28     27     26     25     24     23     22     21     20     19     18     17     16                 
 *              meaning       _TR    -      -      -      -      -      _SPE   _SPW    _HLT   PGM    _MAW   _IRW   _RdE   _RdW   _RcE   _RcW
 *              bit position  15     14     13     12     11     10     09     08     07     06     05     04     03     02     01     00
 *              meaning       _RbE   _RbW   _RaE   _RaW   _PCE   _PCW   _ME    _MW    PCC    _ALE   _ALW   _ALB   ALS2   ALS1   ALS0   ALC
 */


#define ALC  ((uint32_t)1 << 0)
#define ALS0 ((uint32_t)1 << 1)
#define ALS1 ((uint32_t)1 << 2)
#define ALS2 ((uint32_t)1 << 3)
#define _ALB ((uint32_t)1 << 4)
#define _ALW ((uint32_t)1 << 5)
#define _ALE ((uint32_t)1 << 6)
#define PCC  ((uint32_t)1 << 7)
#define _MW  ((uint32_t)1 << 8)
#define _ME  ((uint32_t)1 << 9)
#define _PCW ((uint32_t)1 << 10)
#define _PCE ((uint32_t)1 << 11)
#define _RaW ((uint32_t)1 << 12)
#define _RaE ((uint32_t)1 << 13)
#define _RbW ((uint32_t)1 << 14)
#define _RbE ((uint32_t)1 << 15)

#define _RcW ((uint32_t)1 << 16)
#define _RcE ((uint32_t)1 << 17)
#define _RdW ((uint32_t)1 << 18)
#define _RdE ((uint32_t)1 << 19)
#define _IRW ((uint32_t)1 << 20)
#define _MAW ((uint32_t)1 << 21)
#define  PGM ((uint32_t)1 << 22)
#define _HLT ((uint32_t)1 << 23)
#define _SPW ((uint32_t)1 << 24)
#define _SPE ((uint32_t)1 << 25)

#define _TR  ((uint32_t)1 << 31)

#define ALS(S) ((uint32_t)S << 1)

#define B_MINUS_A 0b001
#define A_MINUS_B 0b010
#define A_PLUS_B  0b011
#define A_XOR_B   0b100
#define A_OR_B    0b101
#define A_AND_B   0b110


#define INC_A     0b000
#define NOT_A     0b111



/* EEPROM address:  bit position     12       11      10  ....   8      7   .....    0
 *                  meaning       flags    carry     (microtime) T              opcode
 */


#define CARRY_ADDR (1 << 11)
#define FLAGS_ADDR (1 << 12)

#define ins_eeprom_address(h, carry, flags, T) (opcode | (carry ? CARRY_ADDR : 0) | (flags ? FLAGS_ADDR : 0) | (T << 8)) 


#define MOV 0b00
#define LOD 0b01
#define STO 0b10


#define Ra  0b000
#define Rb  0b001
#define Rc  0b010
#define Rd  0b011
#define SP  0b100
#define PC  0b101
#define SPi 0b110
#define IMM 0b111


#define OPCODE(op,dreg,sreg) (((op) << 6) | ((dreg) << 3) | (sreg))
#define ALU_OPCODE(with_carry,S,reg) ((0b11 << 6) | (with_carry ? 1 << 5 : 0) | ((S & 0b111) << 2) | (reg & 0b11))


#ifdef CHECK_COVERAGE
uint8_t write_mask[32];
#endif

uint32_t inline flip_active_lows(uint32_t microcode_word) {

  microcode_word ^= (_ALB | _ALW | _ALE | _SPW | _SPE | _PCW | _PCE | _RaW | _RaE | _RbW | _RbE | _RcW | _RcE | _RdW | _RdE | _MAW | _IRW | _HLT | _MW | _ME | _TR);
  return microcode_word;
}

uint32_t _E(uint32_t reg) {

  switch (reg) {
    case Ra: return _RaE;
    case Rb: return _RbE;
    case Rc: return _RcE;
    case Rd: return _RdE;
    case SP: return _SPE;
    case PC: return _PCE;
    default: return 0; 
  }
}

uint32_t _W(uint8_t reg) {

  switch (reg) {
    case Ra: return _RaW;
    case Rb: return _RbW;
    case Rc: return _RcW;
    case Rd: return _RdW;
    case SP: return _SPW;
    case PC: return _PCW;
    default: return 0;
  }
}

#define FETCH0 (_PCE | _MAW)
#define FETCH1 (PGM | _ME | _IRW | PCC)

uint32_t microcode[8] = {FETCH0,FETCH1,_TR,0,0,0,0,0};


uint32_t *MICROCODE0() {
  microcode[2] = _TR;
  microcode[3] = microcode[4] = microcode[5] = microcode[6] = microcode[7] = 0;
  return microcode;
}

uint32_t *MICROCODE1(uint32_t c1) {
  microcode[2] = c1 | _TR;
  microcode[3] = microcode[4] = microcode[5] = microcode[6] = microcode[7] = 0;
  return microcode;
}

uint32_t *MICROCODE2(uint32_t c1, uint32_t c2) {
  microcode[2] = c1;
  microcode[3] = c2 | _TR;
  microcode[4] = microcode[5] = microcode[6] = microcode[7] = 0;
  return microcode;
}

uint32_t *MICROCODE3(uint32_t c1,uint32_t c2,uint32_t c3) {
  microcode[2] = c1;
  microcode[3] = c2;
  microcode[4] = c3 | _TR;
  microcode[5] = microcode[6] = microcode[7] = 0;
  return microcode;
}

uint32_t *MICROCODE4(uint32_t c1,uint32_t c2,uint32_t c3, uint32_t c4) {
  microcode[2] = c1;
  microcode[3] = c2;
  microcode[4] = c3;
  microcode[5] = c4 | _TR;
  microcode[6] = microcode[7] = 0;
  return microcode;
}



void write_conditional_instruction(uint16_t opcode, bool carry, bool flags, uint32_t microcode[], uint8_t rom_no) {

  for (uint8_t T = 0; T < 8; T++) {

    uint16_t eeprom_address = ins_eeprom_address(opcode, carry, flags, T);
    uint8_t eeprom_byte = (flip_active_lows(microcode[T]) >> (8*rom_no)) & 0xFF;
    MyEEPROM.write_eeprom(eeprom_address, eeprom_byte);
    
    #ifdef CHECK_COVERAGE
    uint8_t bit_no = eeprom_address & 0x7;
    write_mask[(eeprom_address & 0xFF) >> 3] |= (1 << bit_no);
    #endif
  }
}

void write_carrycond_instruction(uint16_t opcode, bool carry, uint32_t microcode[], uint8_t rom_no) {

  write_conditional_instruction(opcode, carry, false, microcode, rom_no);
  write_conditional_instruction(opcode, carry, true, microcode, rom_no);
}

void write_instruction(uint16_t opcode, uint32_t microcode[], uint8_t rom_no) {

  write_carrycond_instruction(opcode, false, microcode, rom_no);
  write_carrycond_instruction(opcode, true, microcode, rom_no);
}

#ifdef INS_MOV 
void write_MOVs(uint8_t rom_no) {

  Serial.print("Writing reg <- reg MOV instructions ");
  for (uint8_t sreg = Ra; sreg <= PC; sreg++) {

    Serial.print(".");
    for (uint8_t dreg = Ra; dreg <= PC; dreg++) {

      if (sreg != dreg) {

        write_instruction(OPCODE(MOV, dreg, sreg), MICROCODE1(_W(dreg) | _E(sreg)), rom_no);
      }
    }
  }
  Serial.println(" done.");

  Serial.print("Writing reg <- imm DATA instructions .");
  for (uint8_t dreg = Ra; dreg <= PC; dreg++) {

    write_instruction(OPCODE(MOV, dreg, IMM), MICROCODE2(_PCE | _MAW | PCC, PGM | _ME | _W(dreg)), rom_no);
  }
  Serial.println(". done.");

  Serial.print("Writing NOP and HLT .");
  write_instruction(OPCODE(MOV, Ra, Ra), MICROCODE0(), rom_no);
  write_instruction(OPCODE(MOV, PC, PC), MICROCODE1(_HLT), rom_no);
  Serial.println(". done.");

  Serial.print("Writing conditional JC, JZ, JO and JN instructions ");
  write_carrycond_instruction(OPCODE(MOV, IMM, 0b000), false, MICROCODE1(PCC), rom_no);
  write_carrycond_instruction(OPCODE(MOV, IMM, 0b000), true, MICROCODE2(_MAW | _PCE | PCC, PGM | _ME | _PCW), rom_no);
  Serial.print(".");
  for (uint8_t flag = 0; flag <= 2; flag++) {
    write_conditional_instruction(OPCODE(MOV, IMM, 1<<flag), false, false, MICROCODE1(PCC), rom_no);
    write_conditional_instruction(OPCODE(MOV, IMM, 1<<flag), true, false, MICROCODE1(PCC), rom_no);
    write_conditional_instruction(OPCODE(MOV, IMM, 1<<flag), false, true, MICROCODE2(_MAW | _PCE | PCC, PGM | _ME | _PCW), rom_no);
    write_conditional_instruction(OPCODE(MOV, IMM, 1<<flag), true, true, MICROCODE2(_MAW | _PCE | PCC, PGM | _ME | _PCW), rom_no);
    Serial.print(".");
  }
  Serial.println(". done.");
  
  Serial.println("42 MOV instructions written.");
  Serial.print("Writing HLT to currently unused opcodes (22 total): MOV IMM, Rd|PC|SPi|IMM (4)  |  MOV SPi, <any_R>|SPi|IMM (8) | MOV <any_R>, SPi (6) | MOV <any_R>, <thesame_R> (except Ra, PC) (4) ");

  write_instruction(OPCODE(MOV, IMM, Rd), MICROCODE1(_HLT), rom_no);
  write_instruction(OPCODE(MOV, IMM, PC), MICROCODE1(_HLT), rom_no);
  write_instruction(OPCODE(MOV, IMM, SPi), MICROCODE1(_HLT), rom_no);
  write_instruction(OPCODE(MOV, IMM, IMM), MICROCODE1(_HLT), rom_no);
  Serial.print(".");
    
  for (uint8_t sreg = Ra; sreg <= IMM; sreg++) {

    write_instruction(OPCODE(MOV, SPi, sreg), MICROCODE1(_HLT), rom_no);
  }
  Serial.print(".");

  for (uint8_t dreg = Ra; dreg <= PC; dreg++) {

    write_instruction(OPCODE(MOV, dreg, SPi), MICROCODE1(_HLT), rom_no);
  }
  Serial.print(".");

  for (uint8_t reg = Rb; reg <= SP; reg++) {

    write_instruction(OPCODE(MOV, reg, reg), MICROCODE1(_HLT), rom_no);    
  }
  Serial.println(". done.");
}
#endif

#ifdef INS_LOD
void write_LODs(uint8_t rom_no) {

  Serial.print("Writing reg <- [reg] LOD instructions ");
  for (uint8_t sreg = Ra; sreg <= PC; sreg++) {

    Serial.print(".");
    for (uint8_t dreg = Ra; dreg <= PC; dreg++) {

      write_instruction(OPCODE(LOD, dreg, sreg), MICROCODE2(_MAW | _E(sreg), ((sreg == Rc) ? PGM : 0) | _ME | _W(dreg)), rom_no);
    }
  }
  Serial.println(" done.");

  Serial.print("Writing reg <- [SPi] POP instructions .");
  for (uint8_t dreg = Ra; dreg <= PC; dreg++) {

    write_instruction(OPCODE(LOD, dreg, SPi), MICROCODE3(_SPE | _ALW | ALC | ALS(A_PLUS_B) | _MAW,  _SPW | _ALE, _W(dreg) | _ME), rom_no); 
  }
  Serial.println(". done.");

  Serial.print("Writing reg <- [IMM] LOD instructions .");
  for (uint8_t dreg = Ra; dreg <= PC; dreg++) {

    write_instruction(OPCODE(LOD, dreg, IMM), MICROCODE3(_MAW | _PCE | PCC, _ME | PGM | _MAW, _ME | _W(dreg)), rom_no); 
  }  
  Serial.println(". done.");

  Serial.println("48 LOD instructions written.");
  Serial.print("Writing HLT to currently unused opcodes (16 total): LOD IMM, [<any_R>|SPi|IMM] (8)  |  LOD SPi, [<any_R>|SPi|IMM] (8) ");  
  for (uint8_t dreg = SPi; dreg <= IMM; dreg++) {
    for (uint8_t sreg = Ra; sreg <= IMM; sreg++) {

      write_instruction(OPCODE(LOD, dreg, sreg), MICROCODE1(_HLT), rom_no); 
    }
    Serial.print(".");
  }  
  Serial.println(" done.");

}
#endif

#ifdef INS_STO
void write_STOs(uint8_t rom_no) {

  Serial.print("Writing [reg] <- reg STO instructions ");
  for (uint8_t sreg = Ra; sreg <= PC; sreg++) {

    Serial.print(".");
    for (uint8_t dreg = Ra; dreg <= PC; dreg++) {

      write_instruction(OPCODE(STO, dreg, sreg), MICROCODE2(_MAW | _E(dreg), _MW | _E(sreg)), rom_no);
    }
  }
  Serial.println(" done.");

  Serial.print("Writing [SPi] <- reg PUSH instructions .");
  for (uint8_t sreg = Ra; sreg <= SP; sreg++) {

    write_instruction(OPCODE(STO, SPi, sreg), MICROCODE3(_SPE | _ALW | ALS(A_MINUS_B), _SPW | _ALE | _MAW, _E(sreg) | _MW), rom_no); 
  }
  Serial.println(". done.");

  Serial.print("Writing CALL instruction .");
  write_instruction(OPCODE(STO, SPi, PC), MICROCODE4(_SPE | _ALW | ALS(A_MINUS_B), _SPW | _ALE | _MAW, _PCE | _MW, _PCW | _RcE), rom_no);
  Serial.println(". done.");

  Serial.print("Writing [IMM] <- reg STO instructions .");
  for (uint8_t sreg = Ra; sreg <= PC; sreg++) {

    write_instruction(OPCODE(STO, IMM, sreg), MICROCODE3(_MAW | _PCE | PCC, _ME | PGM | _MAW, _MW | _E(sreg)), rom_no);
  }
  Serial.println(". done.");

  Serial.println("48 STO instructions written.");
  Serial.print("Writing HLT to currently unused opcodes (16 total): STO [<any_R>|SPi|IMM] <- IMM (8)  |  STO [<any_R>|SPi|IMM] <- SPi (8) ");

  for (uint8_t sreg = SPi; sreg <= IMM; sreg++) {
    for (uint8_t dreg = Ra; dreg <= IMM; dreg++) {

      write_instruction(OPCODE(STO, dreg, sreg), MICROCODE1(_HLT), rom_no); 
    }
    Serial.print(".");
  }  
  Serial.println(" done.");
}
#endif

#ifdef INS_ALU
void write_ALU_instructions(uint8_t rom_no) {

  Serial.print("Writing INC reg <- reg + 1 and DEC reg <- reg - 1 instructions .");
  for (uint8_t reg = Ra; reg <= Rd; reg++) {

    write_instruction(ALU_OPCODE(false, INC_A, reg), MICROCODE2(_E(reg) | ALS(A_PLUS_B) | ALC | _ALW, _W(reg) | _ALE), rom_no);
  }
  Serial.print(".");
  
  for (uint8_t reg = Ra; reg <= Rd; reg++) {

    write_instruction(ALU_OPCODE(true, INC_A, reg), MICROCODE2(_E(reg) | ALS(A_MINUS_B) | _ALW, _W(reg) | _ALE), rom_no);
  }
  Serial.println(". done.");

  Serial.print("Writing ADD|ADC reg <- reg + Rb instructions .");
  for (uint8_t reg = Ra; reg <= Rd; reg++) {

    write_instruction(ALU_OPCODE(false, A_PLUS_B, reg), MICROCODE2(_E(reg) | _ALB | ALS(A_PLUS_B) | _ALW, _W(reg) | _ALE), rom_no);
    write_carrycond_instruction(ALU_OPCODE(true, A_PLUS_B, reg), false, MICROCODE2(_E(reg) | _ALB | ALS(A_PLUS_B) | _ALW, _W(reg) | _ALE), rom_no);
    write_carrycond_instruction(ALU_OPCODE(true, A_PLUS_B, reg), true, MICROCODE2(_E(reg) | _ALB | ALS(A_PLUS_B) | _ALW | ALC, _W(reg) | _ALE), rom_no);    
  }
  Serial.println(". done.");

  Serial.print("Writing SUB|SBC reg <- reg - Rb instructions .");
  for (uint8_t reg = Ra; reg <= Rd; reg++) {

    write_instruction(ALU_OPCODE(false, A_MINUS_B, reg), MICROCODE2(_E(reg) | _ALB | ALC | ALS(A_MINUS_B) | _ALW, _W(reg) | _ALE), rom_no);
    write_carrycond_instruction(ALU_OPCODE(true, A_MINUS_B, reg), false, MICROCODE2(_E(reg) | _ALB | ALS(A_MINUS_B) | _ALW, _W(reg) | _ALE), rom_no);
    write_carrycond_instruction(ALU_OPCODE(true, A_MINUS_B, reg), true, MICROCODE2(_E(reg) | _ALB | ALS(A_MINUS_B) | _ALW | ALC, _W(reg) | _ALE), rom_no);    
  }
  Serial.println(". done.");

  Serial.print("Writing SUB|SBC reg <- Rb - reg instructions .");
  for (uint8_t reg = Ra; reg <= Rd; reg++) {

    write_instruction(ALU_OPCODE(false, B_MINUS_A, reg), MICROCODE2(_E(reg) | _ALB | ALC | ALS(B_MINUS_A) | _ALW, _W(reg) | _ALE), rom_no);
    write_carrycond_instruction(ALU_OPCODE(true, B_MINUS_A, reg), false, MICROCODE2(_E(reg) | _ALB | ALS(B_MINUS_A) | _ALW, _W(reg) | _ALE), rom_no);
    write_carrycond_instruction(ALU_OPCODE(true, B_MINUS_A, reg), true, MICROCODE2(_E(reg) | _ALB | ALS(B_MINUS_A) | _ALW | ALC, _W(reg) | _ALE), rom_no);    
  }
  Serial.println(". done.");

  Serial.print("Writing AND reg <- reg & Rb instructions .");
  for (uint8_t reg = Ra; reg <= Rd; reg++) {

    write_instruction(ALU_OPCODE(false, A_AND_B, reg), MICROCODE2(_E(reg) | _ALB | ALS(A_AND_B) | _ALW, _W(reg) | _ALE), rom_no);
  }
  Serial.println(". done.");
  
  Serial.print("Writing OR reg <- reg | Rb instructions .");
  for (uint8_t reg = Ra; reg <= Rd; reg++) {

    write_instruction(ALU_OPCODE(false, A_OR_B, reg), MICROCODE2(_E(reg) | _ALB | ALS(A_OR_B) | _ALW, _W(reg) | _ALE), rom_no);
  }
  Serial.println(". done.");
  
  Serial.print("Writing XOR reg <- reg ^ Rb instructions .");
  for (uint8_t reg = Ra; reg <= Rd; reg++) {

    write_instruction(ALU_OPCODE(false, A_XOR_B, reg), MICROCODE2(_E(reg) | _ALB | ALS(A_XOR_B) | _ALW, _W(reg) | _ALE), rom_no);
  }
  Serial.println(". done.");

  Serial.print("Writing NOT reg <- !reg instructions .");
  for (uint8_t reg = Ra; reg <= Rd; reg++) {

    write_instruction(ALU_OPCODE(false, NOT_A, reg), MICROCODE2(_E(reg) | ALS(B_MINUS_A) | _ALW, _W(reg) | _ALE), rom_no);
  }
  Serial.println(". done.");

  Serial.print("Writing CMP Rb, reg instructions .");
  for (uint8_t reg = Ra; reg <= Rd; reg++) {

    write_instruction(ALU_OPCODE(true, A_OR_B, reg), MICROCODE1(_E(reg) | ALC | _ALB | ALS(B_MINUS_A) | _ALW), rom_no);
  }
  Serial.println(". done.");

  Serial.print("Writing CMP reg, Rb instructions .");
  for (uint8_t reg = Ra; reg <= Rd; reg++) {

    write_instruction(ALU_OPCODE(true, A_AND_B, reg), MICROCODE1(_E(reg) | ALC | _ALB | ALS(A_MINUS_B) | _ALW), rom_no);
  }
  Serial.println(". done.");

  Serial.print("Writing TST reg instructions .");
  for (uint8_t reg = Ra; reg <= Rd; reg++) {

    write_instruction(ALU_OPCODE(true, NOT_A, reg), MICROCODE1(_E(reg) | ALS(A_PLUS_B) | _ALW), rom_no);
  }
  Serial.println(". done.");

  Serial.println("Written 60 ALU instructions.");
  Serial.print("Writing HLT to currently unused instructions (4 total): XORC .");
  for (uint8_t reg = Ra; reg <= Rd; reg++) {
    write_instruction(ALU_OPCODE(true, A_XOR_B, reg), MICROCODE1(_HLT), rom_no);
  }
  Serial.println(". done.");
}
#endif

#ifdef CHECK_COVERAGE
char buf[80];
#endif

// the setup function runs once when you press reset or power the board
void setup() {
  Serial.begin(115200);
  Serial.print("About to program microcode EEPROM no. ");
  Serial.print(ROM_NO);
  Serial.print(". Press 'y' to continue ... ");
  while (Serial.available() <= 0);
  char answer = Serial.read();
  Serial.println(answer);

  if (answer == 'y') {

    #ifdef CHECK_COVERAGE
    for (uint16_t c=0; c <1024; c++) {

        write_mask[c] = 0;
    }
    #endif
    
    MyEEPROM.init();
    
    #ifdef INS_MOV
    write_MOVs(ROM_NO);
    #endif
  
    #ifdef INS_LOD
    write_LODs(ROM_NO);
    #endif
  
    #ifdef INS_STO
    write_STOs(ROM_NO);
    #endif
    
    #ifdef INS_ALU
    write_ALU_instructions(ROM_NO);
    #endif
  
    #ifdef DUMP
    MyEEPROM.dump_eeprom(0, 0x1FFF);
    #endif

    #ifdef CHECK_COVERAGE
    Serial.println("Output mask");
    for (int c=0; c < 32; c+=16) {

      sprintf(buf, "%02x %02x %02x %02x %02x %02x %02x %02x  %02x %02x %02x %02x %02x %02x %02x %02x",
      write_mask[c], write_mask[c+1], write_mask[c+2], write_mask[c+3], write_mask[c+4], write_mask[c+5], write_mask[c+6], write_mask[c+7],
      write_mask[c+8], write_mask[c+9], write_mask[c+10], write_mask[c+11], write_mask[c+12], write_mask[c+13], write_mask[c+14], write_mask[c+15]);
      Serial.println(buf);
    }
    #endif
  }  
  Serial.println("Have a nice day.");
}

// the loop function runs over and over again forever
void loop() {
}

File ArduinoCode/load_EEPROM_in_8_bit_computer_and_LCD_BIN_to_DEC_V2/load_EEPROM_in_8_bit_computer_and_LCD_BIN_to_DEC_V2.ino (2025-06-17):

#include <LiquidCrystal.h>
/* This sketch includes both code for the LCD to work, and also code for the "bootloader"

*/
// data to send to 8 bit computer. Maximum of bytes to send to RAM is 255
byte data[] = { 0x0f, 0x0a, 0x17, 0x0a, 0x1f, 0x00, 0xe2, 0x38, 0x0b, 0x03, 0x2d, 0xcf, 0x2f, 0x06};

const int rs = 12, en = 11, d4 = 5, d5 = 4, d6 = 3, d7 = 2;
LiquidCrystal lcd(rs, en, d4, d5, d6, d7);

byte a0;
byte a1;
byte a2;
byte a3;
byte a4;
byte a5;
byte a6;
byte a7;


//Pin connected to SH_CP of 74HC595
int clockPin = 10;
////Pin connected to DS of 74HC595
int dataPin = 9;
//Pin connected to ST_CP of 74HC595
int latchPin = 8;
//Pin used to request a new byte from Arduino to the 74HC595
int requestPin = 7;
//Pin used for reseting the index that controls which byte is to be written to the 74HC595
int reset_Pin = 13;
//Pin used for disabling the RAM OE pin so the 74HC595 can feed its data to the EEPROM
int disableRAM_OE_Pin = 6;

int lastRequestState = 0;
int lastResetState = 0;

bool resetState = false;
bool requestState = false;
bool disableRAM_OE = false;

byte byteRead1;
byte byteRead2;
byte completeByte;
byte b1 = 0;
byte b2 = 0;

int index = 0;
int i;

void setup() {
  pinMode(reset_Pin, INPUT);
  pinMode(latchPin, OUTPUT);
  pinMode(clockPin, OUTPUT);
  pinMode(dataPin, OUTPUT);
  pinMode(requestPin, INPUT);
  pinMode(disableRAM_OE_Pin, OUTPUT);

  int i = 0;
  Serial.begin(57600); //this baudrate must be the same in the Proccesing sketch

  lcd.begin(16, 2);
  //set pins to output so you can control the shift register
}

void loop() {

  if (Serial.available() > 0)
  {
    byteRead1 = Serial.read();
    delay(1);          //delay(1)
    byteRead2 = Serial.read();
    //Serial.write(byteRead1);
    //Serial.write(byteRead2);
    

    if (byteRead1 >= 65 && byteRead1 <= 70)
      byteRead1 -= 55;
    else if (byteRead1 >= 97 && byteRead1 <= 102)
      byteRead1 -= 87;
    if (byteRead1 >= 48 && byteRead1 <= 57)
      byteRead1 -= 48;

    byteRead1 *= 16;

    if (byteRead2 >= 65 && byteRead2 <= 70)
      byteRead2 -= 55;
    else if (byteRead2 >= 97 && byteRead2 <= 102)
      byteRead2 -= 87;
    if (byteRead2 >= 48 && byteRead2 <= 57)
      byteRead2 -= 48;

    completeByte = byteRead1 + byteRead2;
    data[index] = completeByte;

    Serial.write(completeByte);
    index++;
  }
  else if (Serial.available() == 0){
    
    a0 = highOrLow(0, 0b10000000);
    a1 = highOrLow(1, 0b1000000);
    a2 = highOrLow(2, 0b100000);
    a3 = highOrLow(3, 0b10000);
    a4 = highOrLow(4, 0b1000);
    a5 = highOrLow(5, 0b100);
    a6 = highOrLow(6, 0b10);
    a7 = highOrLow(7, 0b1);
    
    b1 = a0 | a1 | a2 | a3 | a4 | a5 | a6 | a7;
    
    //lcd.clear();
    lcd.setCursor(0, 0);
    lcd.print(0);
    lcd.setCursor(1, 0);
    lcd.print(0);
    lcd.setCursor(2, 0);
    lcd.print(0);

    if (b1 < 10)
      lcd.setCursor(2, 0);
    else if (b1 < 100)
      lcd.setCursor(1, 0);
    else if (b1 < 1000)
      lcd.setCursor(0, 0);

    lcd.print(b1);
    if(b1 != b2)
    {
      Serial.write(b1);        // använda denna om jag vill se värderna i processing    ////  ta bort det här om du vill se i processing rätt bytes
      //Serial.println(b1);   // använda denna om jag vill se värderna i "seriell monitor" i Arduino
    }
    b2 = b1;
    
    if (!disableRAM_OE)
    {
      delay(5);
    }
     
    //Serial.println(disableRAM_OE);
    //Serial.println(digitalRead(reset_Pin));
    //Serial.println(resetState);
  }

  requestState = digitalRead(requestPin);
  resetState = digitalRead(reset_Pin);

  if (requestState != lastRequestState && i < sizeof(data))
  {
    if (requestState == LOW)
    {
      //Serial.println(digitalRead(requestPin));
      disableRAM_OE = true;
      digitalWrite(disableRAM_OE_Pin, disableRAM_OE);
      // take the latchPin low so
      // the LEDs don't change while you're sending in bits:
      digitalWrite(latchPin, LOW);
      // shift out the bits:
      //Serial.println("-------------");
      //Serial.println(data[i], HEX);
      shiftOut(dataPin, clockPin, MSBFIRST, data[i]);
      i++;

      //take the latch pin high so the LEDs will light up:
      digitalWrite(latchPin, HIGH);
    }
    else
    {

    }
  }

  lastRequestState = requestState;

  if (i >= sizeof(data) - 1)
  {
    disableRAM_OE = false;
    delay(1);
    digitalWrite(disableRAM_OE_Pin, disableRAM_OE);
  }

  if (resetState != lastResetState)
  {
    if (resetState == HIGH)
    {
      i = 0;
    }
  }

  lastResetState = resetState;

}

byte highOrLow(int pin, byte value)
{
  if (analogRead(pin) > 500)
    return value;
  else
    return 0b00000000;
}

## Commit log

2025-06-17 added all module schematics
2025-06-17 added Arduino Code
2025-06-17 added kicad
    [8-bit computer_Boot_loader.kicad_pcb, 8-bit computer_Boot_loader.kicad_sch, 8-bit computer_Buss.kicad_pcb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]
